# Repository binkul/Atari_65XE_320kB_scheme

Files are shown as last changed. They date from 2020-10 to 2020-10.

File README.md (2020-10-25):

# Atari_65XE_320kB_scheme

It is working, but there is problem with video. The image on the monitor is not clear. There is a lot of white vertical stripes - probably wrong GND project. 
There can be used up to four diffrent OS and eight internal languages, like MAC65, Action!, Basic XE, XL. On Board GTIA fixer and 256kB extra RAM.

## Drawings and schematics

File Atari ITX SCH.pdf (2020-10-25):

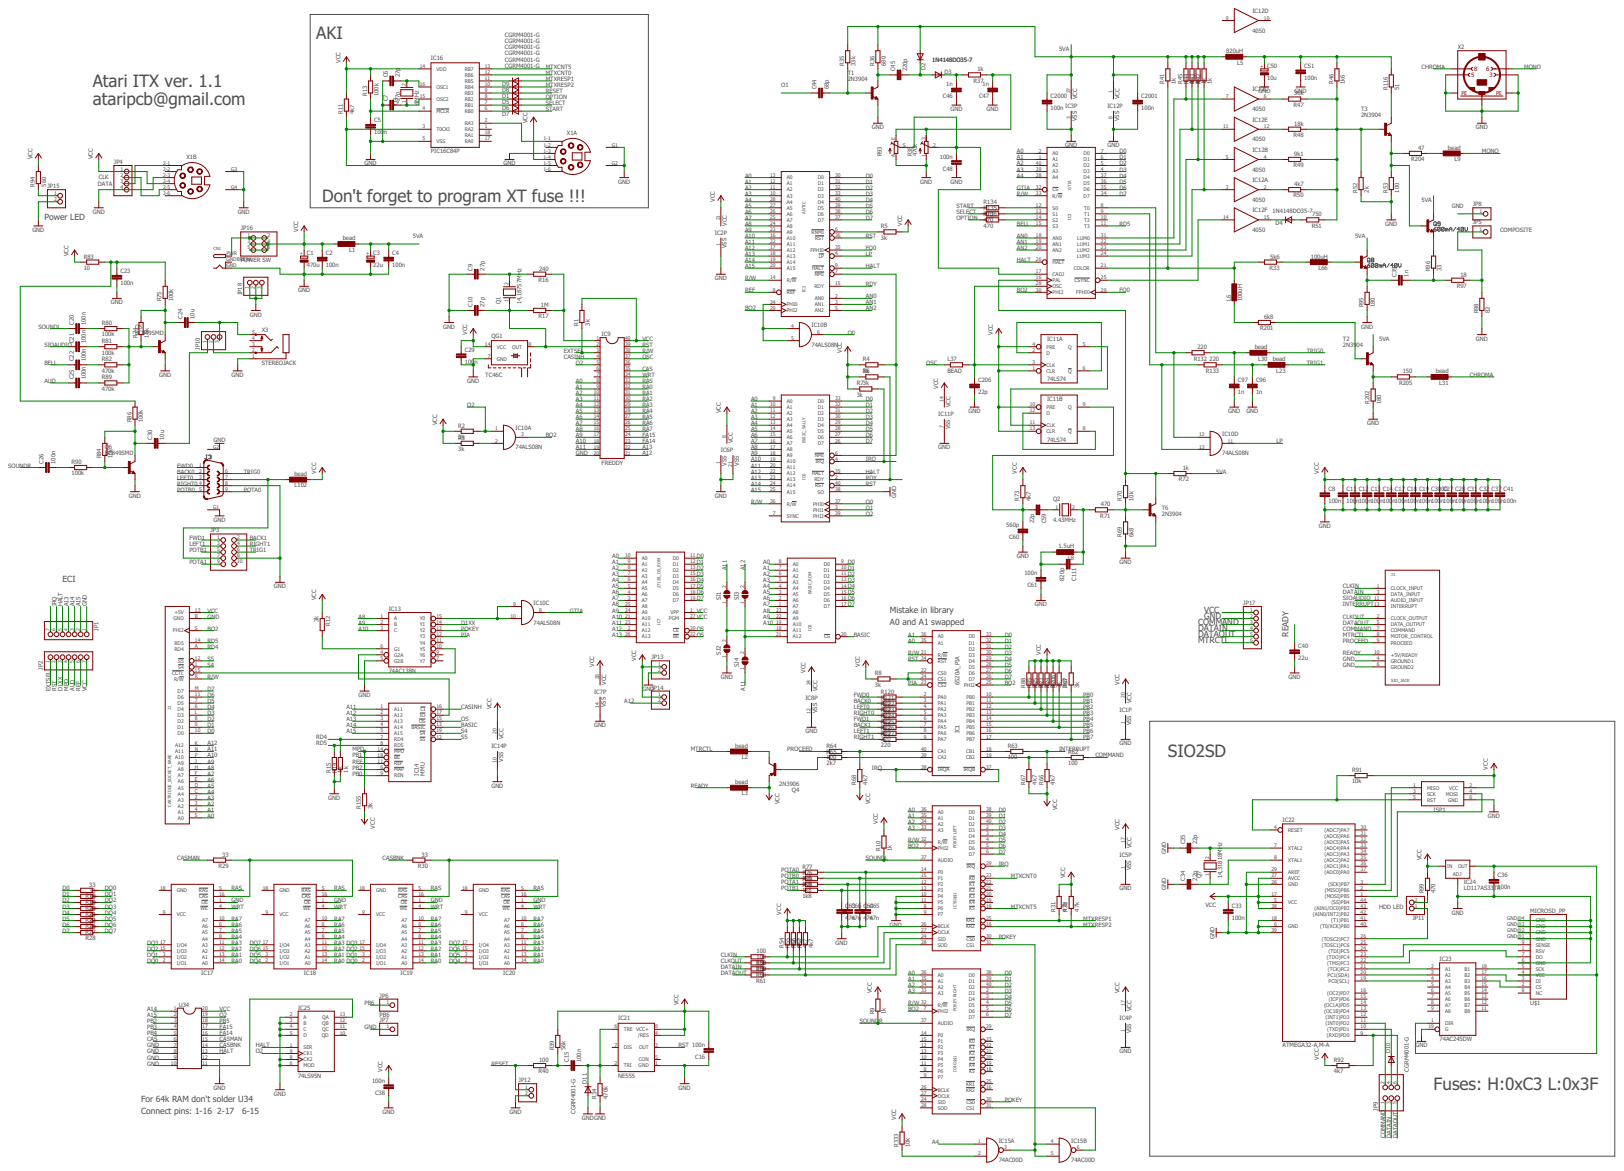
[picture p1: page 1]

Don't forget to program XT fuse !!!

VSS VSS VCC VSS

VCC VSS

For 64k RAM don't solder U34
Connect pins: 1-16 2-17 6-15

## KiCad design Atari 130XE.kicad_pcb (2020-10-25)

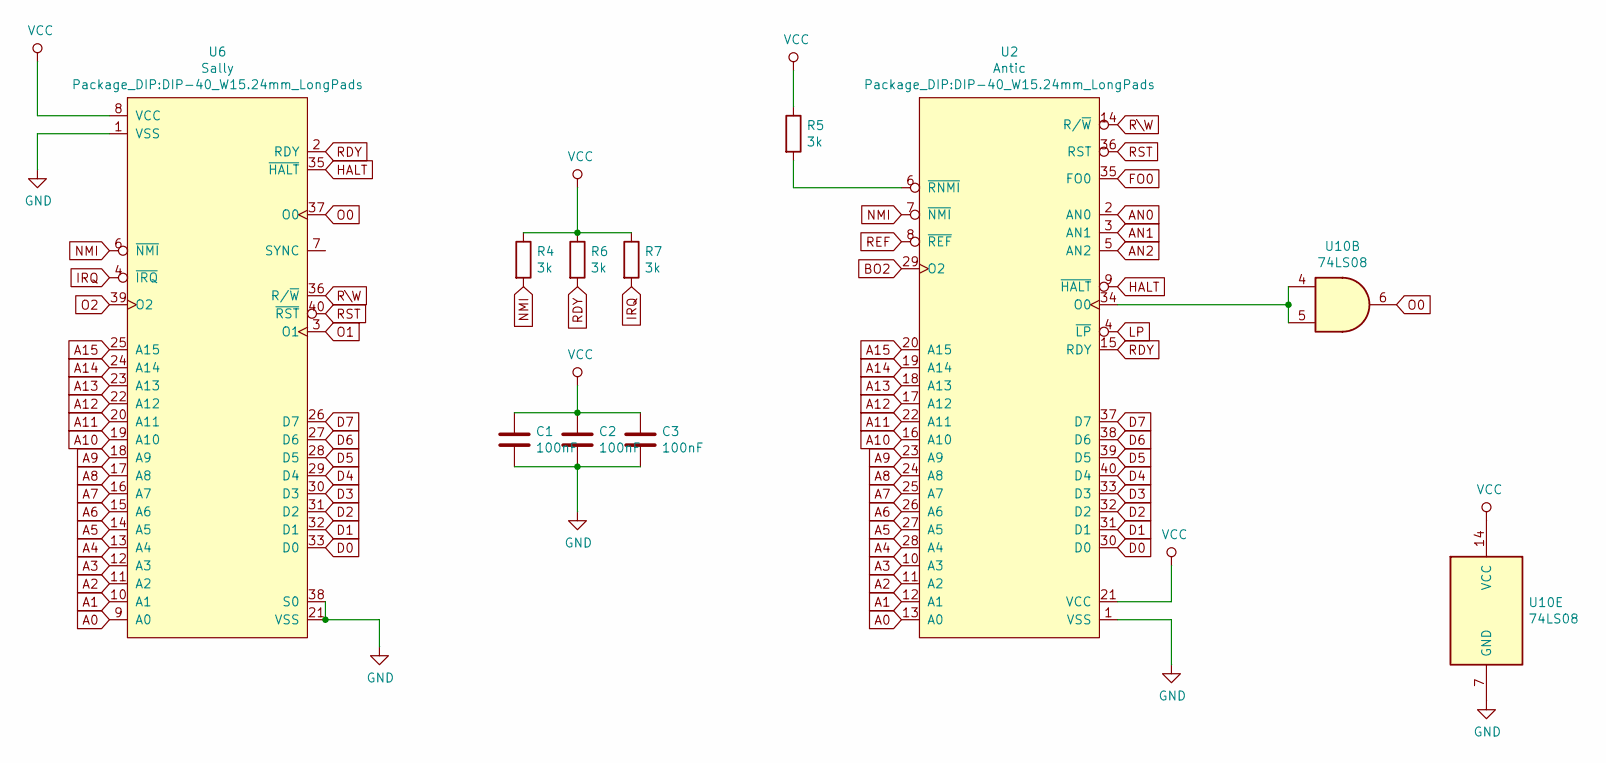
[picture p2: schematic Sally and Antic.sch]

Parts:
C1, C2, C3: 100nF; C_Disc_D5.0mm_W2.5mm_P5.00mm
R4, R5, R6, R7: 3k; R_1206_3216Metric_Pad1.42x1.75mm_HandSolder
U2: Antic; DIP-40_W15.24mm_LongPads
U6: Sally; DIP-40_W15.24mm_LongPads
U10: 74LS08; DIP-14_W7.62mm_Socket

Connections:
A0: U2.13 (A0), U6.9 (A0); also elsewhere on the board
A1: U2.12 (A1), U6.10 (A1); also elsewhere on the board
A2: U2.11 (A2), U6.11 (A2); also elsewhere on the board
A3: U2.10 (A3), U6.12 (A3); also elsewhere on the board
A4: U2.28 (A4), U6.13 (A4); also elsewhere on the board
A5: U2.27 (A5), U6.14 (A5); also elsewhere on the board
A6: U2.26 (A6), U6.15 (A6); also elsewhere on the board
A7: U2.25 (A7), U6.16 (A7); also elsewhere on the board
A8: U2.24 (A8), U6.17 (A8); also elsewhere on the board
A9: U2.23 (A9), U6.18 (A9); also elsewhere on the board
A10: U2.16 (A10), U6.19 (A10); also elsewhere on the board
A11: U2.22 (A11), U6.20 (A11); also elsewhere on the board
A12: U2.17 (A12), U6.22 (A12); also elsewhere on the board
A13: U2.18 (A13), U6.23 (A13); also elsewhere on the board
A14: U2.19 (A14), U6.24 (A14); also elsewhere on the board
A15: U2.20 (A15), U6.25 (A15); also elsewhere on the board
AN0: U2.2 (AN0); also elsewhere on the board
AN1: U2.3 (AN1); also elsewhere on the board
AN2: U2.5 (AN2); also elsewhere on the board
BO2: U2.29 (O2); also elsewhere on the board
D0: U2.30 (D0), U6.33 (D0); also elsewhere on the board
D1: U2.31 (D1), U6.32 (D1); also elsewhere on the board
D2: U2.32 (D2), U6.31 (D2); also elsewhere on the board
D3: U2.33 (D3), U6.30 (D3); also elsewhere on the board
D4: U2.40 (D4), U6.29 (D4); also elsewhere on the board
D5: U2.39 (D5), U6.28 (D5); also elsewhere on the board
D6: U2.38 (D6), U6.27 (D6); also elsewhere on the board
D7: U2.37 (D7), U6.26 (D7); also elsewhere on the board
FO0: U2.35 (FO0); also elsewhere on the board
GND: C1.2, C2.2, C3.2, U2.1 (VSS), U6.1 (VSS), U6.21 (VSS), U6.38 (S0), U10.7 (GND); also elsewhere on the board
HALT: U2.9 (~HALT), U6.35 (~HALT); also elsewhere on the board
IRQ: R7.2, U6.4 (~IRQ); also elsewhere on the board
LP: U2.4 (~LP); also elsewhere on the board
NMI: R4.2, U2.7 (~NMI), U6.6 (~NMI)
unnamed: R5.2, U2.6 (~RNMI)
unnamed: U2.34 (O0), U10.4, U10.5
O0: U6.37 (O0), U10.6
O1: U6.3 (O1); also elsewhere on the board
O2: U6.39 (O2); also elsewhere on the board
RDY: R6.2, U2.15 (RDY), U6.2 (RDY)
REF: U2.8 (~REF); also elsewhere on the board
RST: U2.36 (RST), U6.40 (~RST); also elsewhere on the board
R\W: U2.14 (R/~W), U6.36 (R/~W); also elsewhere on the board
VCC: C1.1, C2.1, C3.1, R4.1, R5.1, R6.1, R7.1, U2.21 (VCC), U6.8 (VCC), U10.14 (VCC); also elsewhere on the board

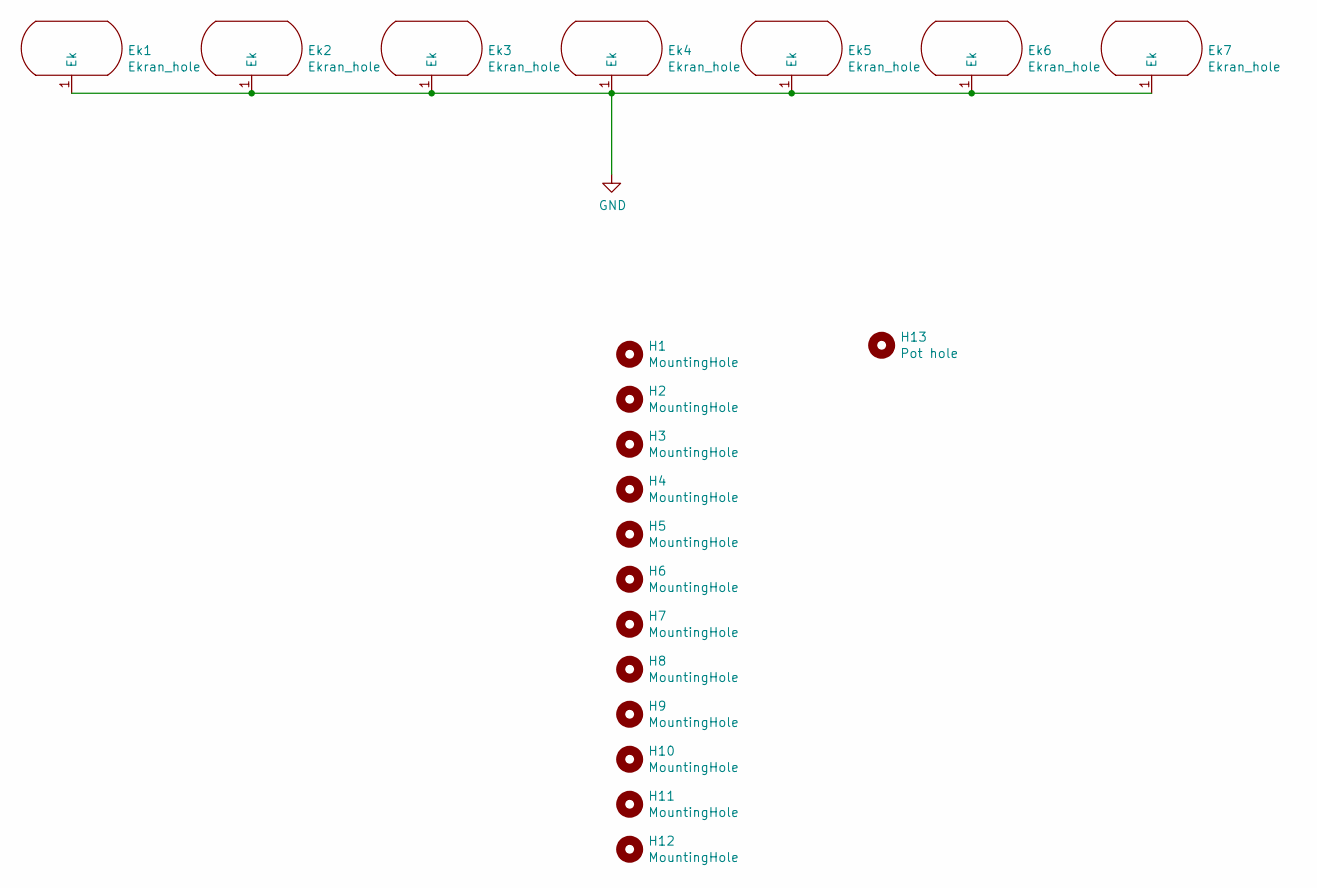
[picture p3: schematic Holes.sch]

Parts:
Ek1, Ek2, Ek3, Ek4, Ek5, Ek6, Ek7: Ekran_hole; Ekran_GND
H1, H2: MountingHole; Big_hole
H3, H4: MountingHole; Medium_hole
H5, H6, H7, H10, H11, H12: MountingHole; Hole_3.4mm
H8, H9: MountingHole; Hole_4.4mm
H13: Pot hole; MountingHole_3.2mm_M3

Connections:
GND: Ek1.1, Ek2.1, Ek3.1, Ek4.1, Ek5.1, Ek6.1, Ek7.1; also elsewhere on the board

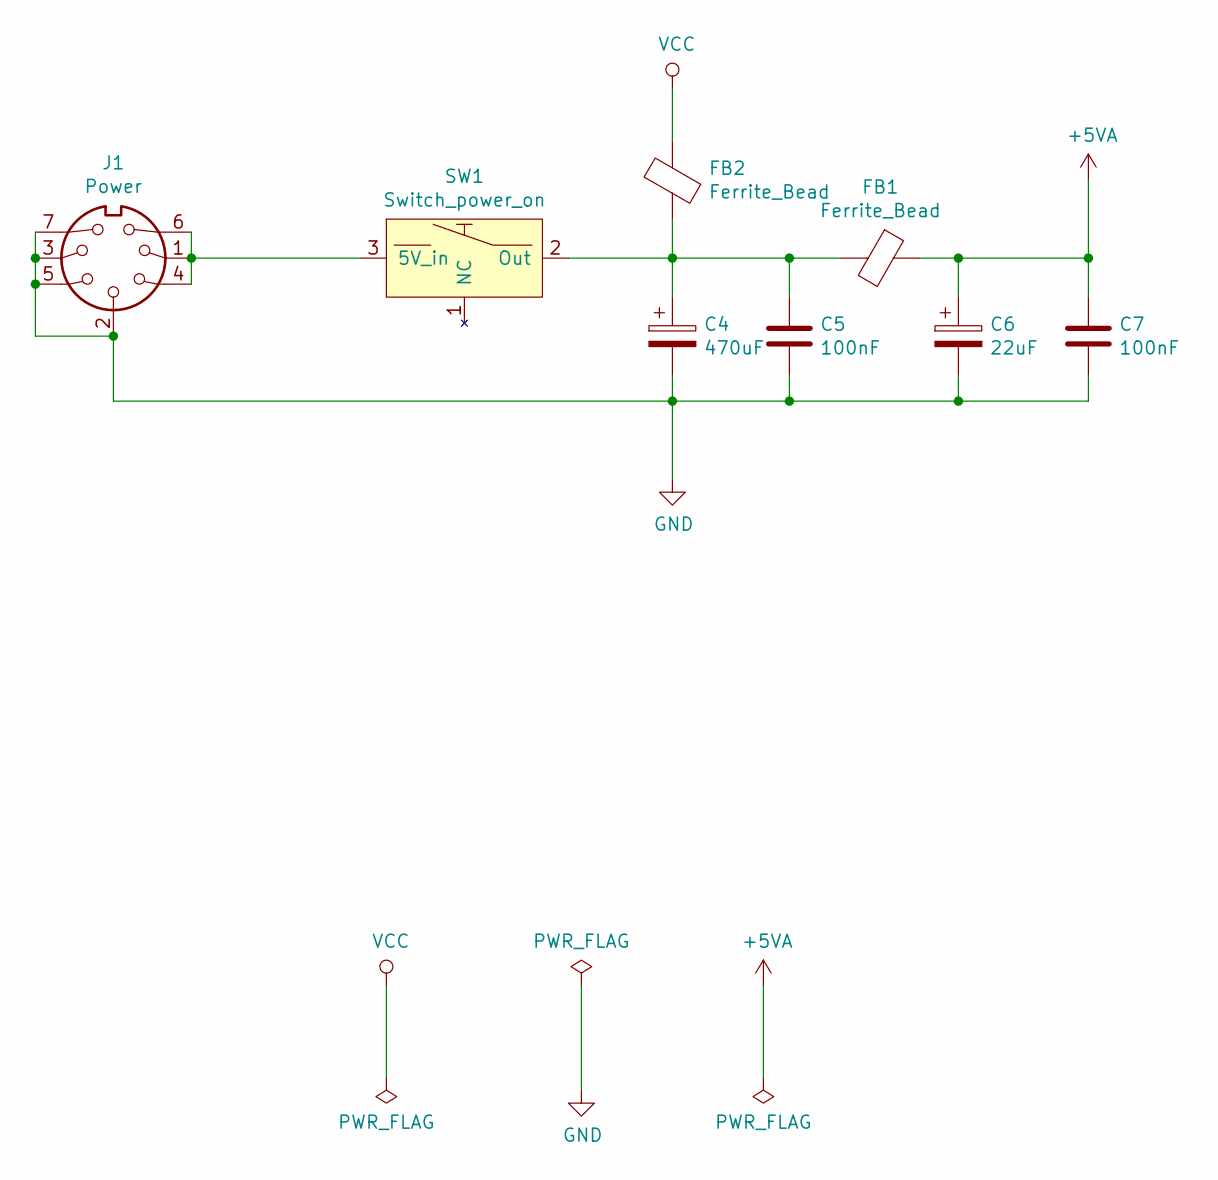
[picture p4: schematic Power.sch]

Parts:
C4: 470uF; CP_Radial_D10.0mm_P5.00mm
C5, C7: 100nF; C_Disc_D5.0mm_W2.5mm_P5.00mm
C6: 22uF; CP_Radial_D5.0mm_P2.00mm
FB1, FB2: Ferrite_Bead; L_Axial_L9.5mm_D4.0mm_P12.70mm_Horizontal_Fastron_SMCC
J1: Power; DIN_7_pin
SW1: Switch_power_on; Switch_ON-OFF

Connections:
+5VA: C6.1, C7.1, FB1.1; also elsewhere on the board
GND: C4.2, C5.2, C6.2, C7.2, J1.2, J1.3, J1.5, J1.7; also elsewhere on the board
unnamed: C4.1, C5.1, FB1.2, FB2.1, SW1.2 (Out)
unnamed: J1.1, J1.4, J1.6, SW1.3 (5V_in)
VCC: FB2.2; also elsewhere on the board

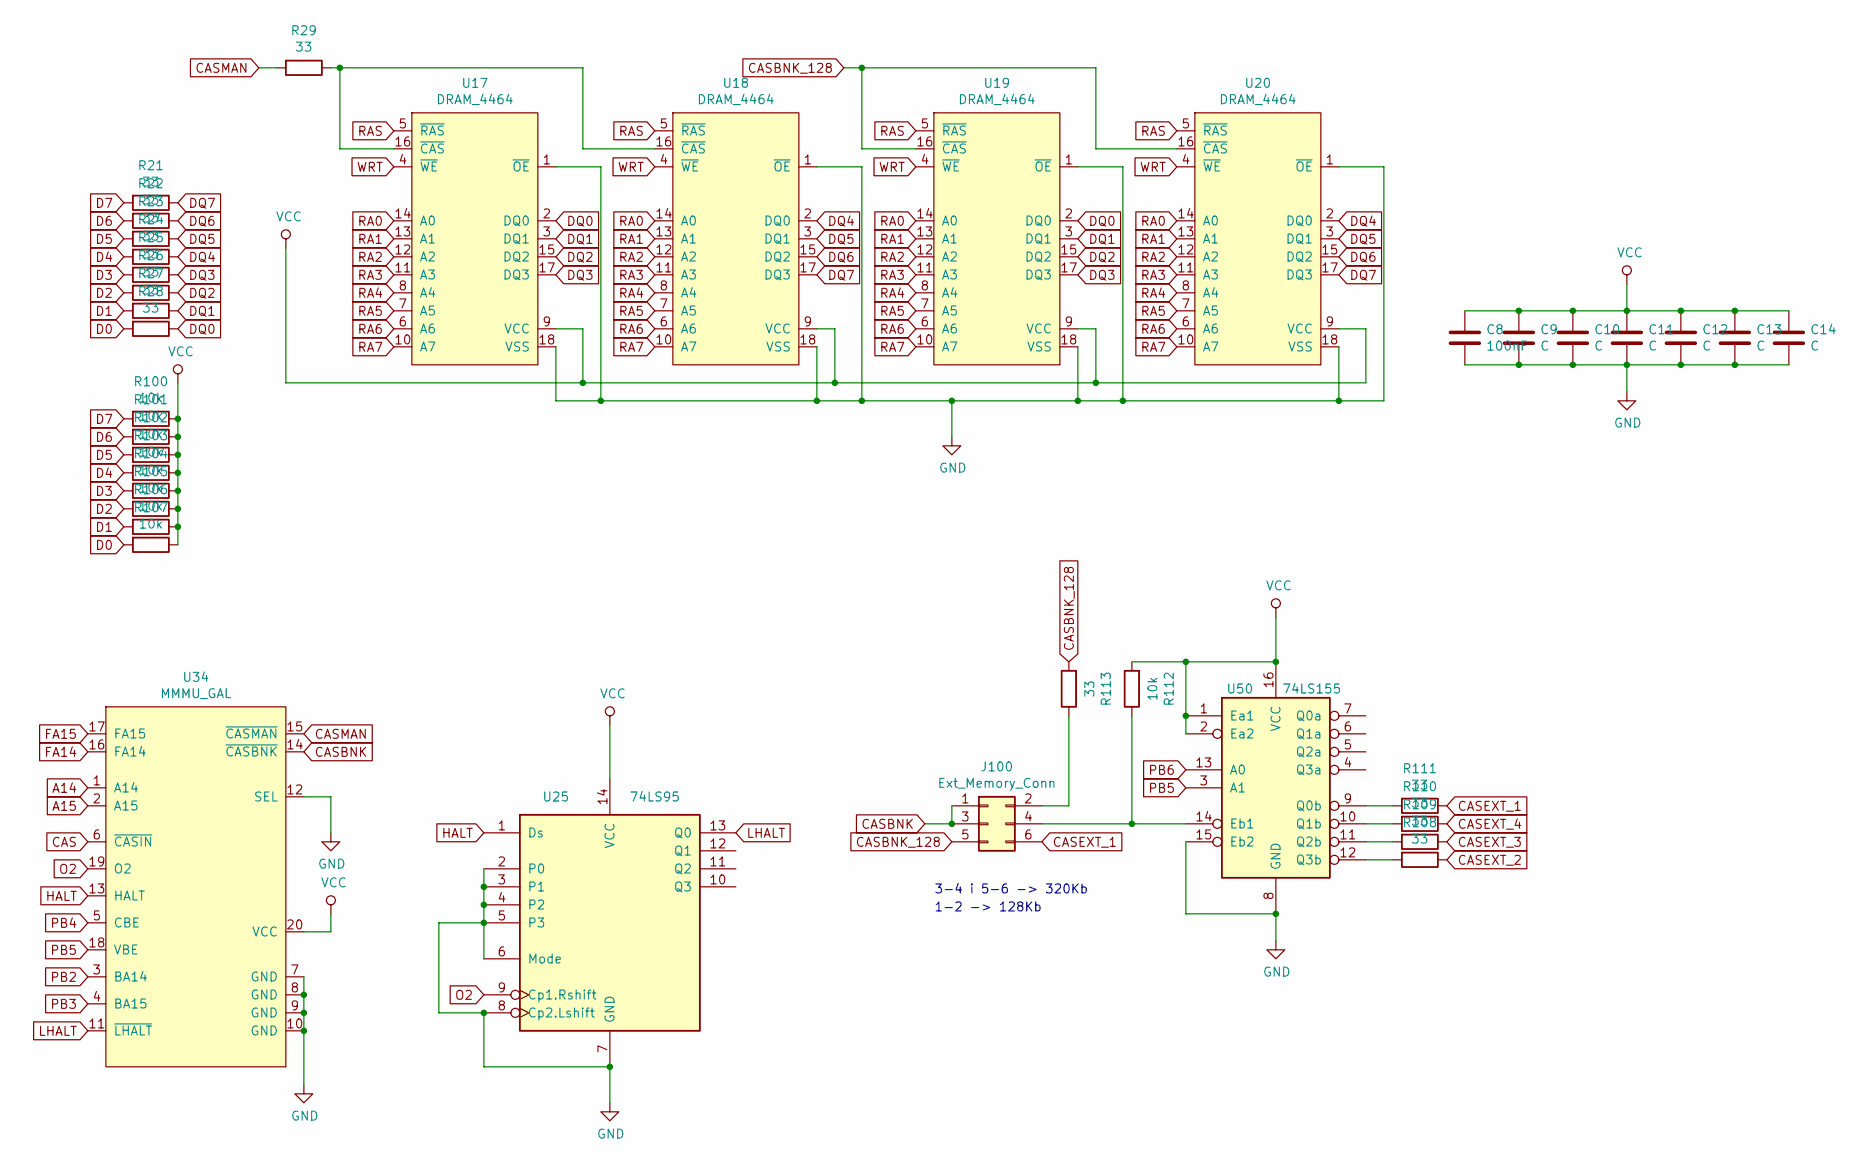
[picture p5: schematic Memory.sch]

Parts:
C8: 100nF; C_Disc_D5.0mm_W2.5mm_P5.00mm
C9, C10, C11, C12, C13, C14: C; C_Disc_D5.0mm_W2.5mm_P5.00mm
J100: Ext_Memory_Conn; PinHeader_2x03_P2.54mm_Vertical
R21, R22, R23, R24, R25, R26, R27, R28, R29, R108, R109, R110, R111, R113: 33; R_1206_3216Metric_Pad1.42x1.75mm_HandSolder
R100, R101, R102, R103, R104, R105, R106, R107, R112: 10k; R_1206_3216Metric_Pad1.42x1.75mm_HandSolder
U17, U18, U19, U20: DRAM_4464; DIP-18_W7.62mm_LongPads
U25: 74LS95; DIP-14_W7.62mm_Socket
U34: MMMU_GAL; DIP-20_W7.62mm_Socket
U50: 74LS155; DIP-16_W7.62mm_Socket

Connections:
A14: U34.1 (A14); also elsewhere on the board
A15: U34.2 (A15); also elsewhere on the board
CAS: U34.6 (~CASIN); also elsewhere on the board
CASBNK: J100.1, J100.3, U34.14 (~CASBNK)
CASBNK_128: J100.5, R113.2, U19.16 (~CAS), U20.16 (~CAS)
CASEXT_1: J100.6, R111.1
CASEXT_2: R108.1; also elsewhere on the board
CASEXT_3: R109.1; also elsewhere on the board
CASEXT_4: R110.1; also elsewhere on the board
CASMAN: R29.2, U34.15 (~CASMAN)
D0: R28.2, R107.2; also elsewhere on the board
D1: R27.2, R106.2; also elsewhere on the board
D2: R26.2, R105.2; also elsewhere on the board
D3: R25.2, R104.2; also elsewhere on the board
D4: R24.2, R103.2; also elsewhere on the board
D5: R23.2, R102.2; also elsewhere on the board
D6: R22.2, R101.2; also elsewhere on the board
D7: R21.2, R100.2; also elsewhere on the board
DQ0: R28.1, U17.2 (DQ0), U19.2 (DQ0); also elsewhere on the board
DQ1: R27.1, U17.3 (DQ1), U19.3 (DQ1); also elsewhere on the board
DQ2: R26.1, U17.15 (DQ2), U19.15 (DQ2); also elsewhere on the board
DQ3: R25.1, U17.17 (DQ3), U19.17 (DQ3); also elsewhere on the board
DQ4: R24.1, U18.2 (DQ0), U20.2 (DQ0); also elsewhere on the board
DQ5: R23.1, U18.3 (DQ1), U20.3 (DQ1); also elsewhere on the board
DQ6: R22.1, U18.15 (DQ2), U20.15 (DQ2); also elsewhere on the board
DQ7: R21.1, U18.17 (DQ3), U20.17 (DQ3); also elsewhere on the board
FA14: U34.16 (FA14); also elsewhere on the board
FA15: U34.17 (FA15); also elsewhere on the board
GND: C8.2, C9.2, C10.2, C11.2, C12.2, C13.2, C14.2, U17.1 (~OE), U17.18 (VSS), U18.1 (~OE), U18.18 (VSS), U19.1 (~OE), U19.18 (VSS), U20.1 (~OE), U20.18 (VSS), U25.2 (P0), U25.3 (P1), U25.4 (P2), U25.5 (P3), U25.6 (Mode), U25.7 (GND), U25.8 (Cp2.Lshift), U34.7 (GND), U34.8 (GND), U34.9 (GND), U34.10 (GND), U34.12 (SEL), U50.8 (GND), U50.15 (Eb2); also elsewhere on the board
HALT: U25.1 (Ds), U34.13 (HALT); also elsewhere on the board
LHALT: U25.13 (Q0), U34.11 (~LHALT)
unnamed: J100.2, R113.1
unnamed: J100.4, R112.1, U50.14 (Eb1)
unnamed: R29.1, U17.16 (~CAS), U18.16 (~CAS)
unnamed: R108.2, U50.12 (Q3b)
unnamed: R109.2, U50.11 (Q2b)
unnamed: R110.2, U50.10 (Q1b)
unnamed: R111.2, U50.9 (Q0b)
O2: U25.9 (Cp1.Rshift), U34.19 (O2); also elsewhere on the board
PB2: U34.3 (BA14); also elsewhere on the board
PB3: U34.4 (BA15); also elsewhere on the board
PB4: U34.5 (CBE); also elsewhere on the board
PB5: U34.18 (VBE), U50.3 (A1); also elsewhere on the board
PB6: U50.13 (A0); also elsewhere on the board
RA0: U17.14 (A0), U18.14 (A0), U19.14 (A0), U20.14 (A0); also elsewhere on the board
RA1: U17.13 (A1), U18.13 (A1), U19.13 (A1), U20.13 (A1); also elsewhere on the board
RA2: U17.12 (A2), U18.12 (A2), U19.12 (A2), U20.12 (A2); also elsewhere on the board
RA3: U17.11 (A3), U18.11 (A3), U19.11 (A3), U20.11 (A3); also elsewhere on the board
RA4: U17.8 (A4), U18.8 (A4), U19.8 (A4), U20.8 (A4); also elsewhere on the board
RA5: U17.7 (A5), U18.7 (A5), U19.7 (A5), U20.7 (A5); also elsewhere on the board
RA6: U17.6 (A6), U18.6 (A6), U19.6 (A6), U20.6 (A6); also elsewhere on the board
RA7: U17.10 (A7), U18.10 (A7), U19.10 (A7), U20.10 (A7); also elsewhere on the board
RAS: U17.5 (~RAS), U18.5 (~RAS), U19.5 (~RAS), U20.5 (~RAS); also elsewhere on the board
VCC: C8.1, C9.1, C10.1, C11.1, C12.1, C13.1, C14.1, R100.1, R101.1, R102.1, R103.1, R104.1, R105.1, R106.1, R107.1, R112.2, U17.9 (VCC), U18.9 (VCC), U19.9 (VCC), U20.9 (VCC), U25.14 (VCC), U34.20 (VCC), U50.1 (Ea1), U50.2 (Ea2), U50.16 (VCC); also elsewhere on the board
WRT: U17.4 (~WE), U18.4 (~WE), U19.4 (~WE), U20.4 (~WE); also elsewhere on the board

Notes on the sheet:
3-4 i 5-6 -> 320Kb
1-2 -> 128Kb

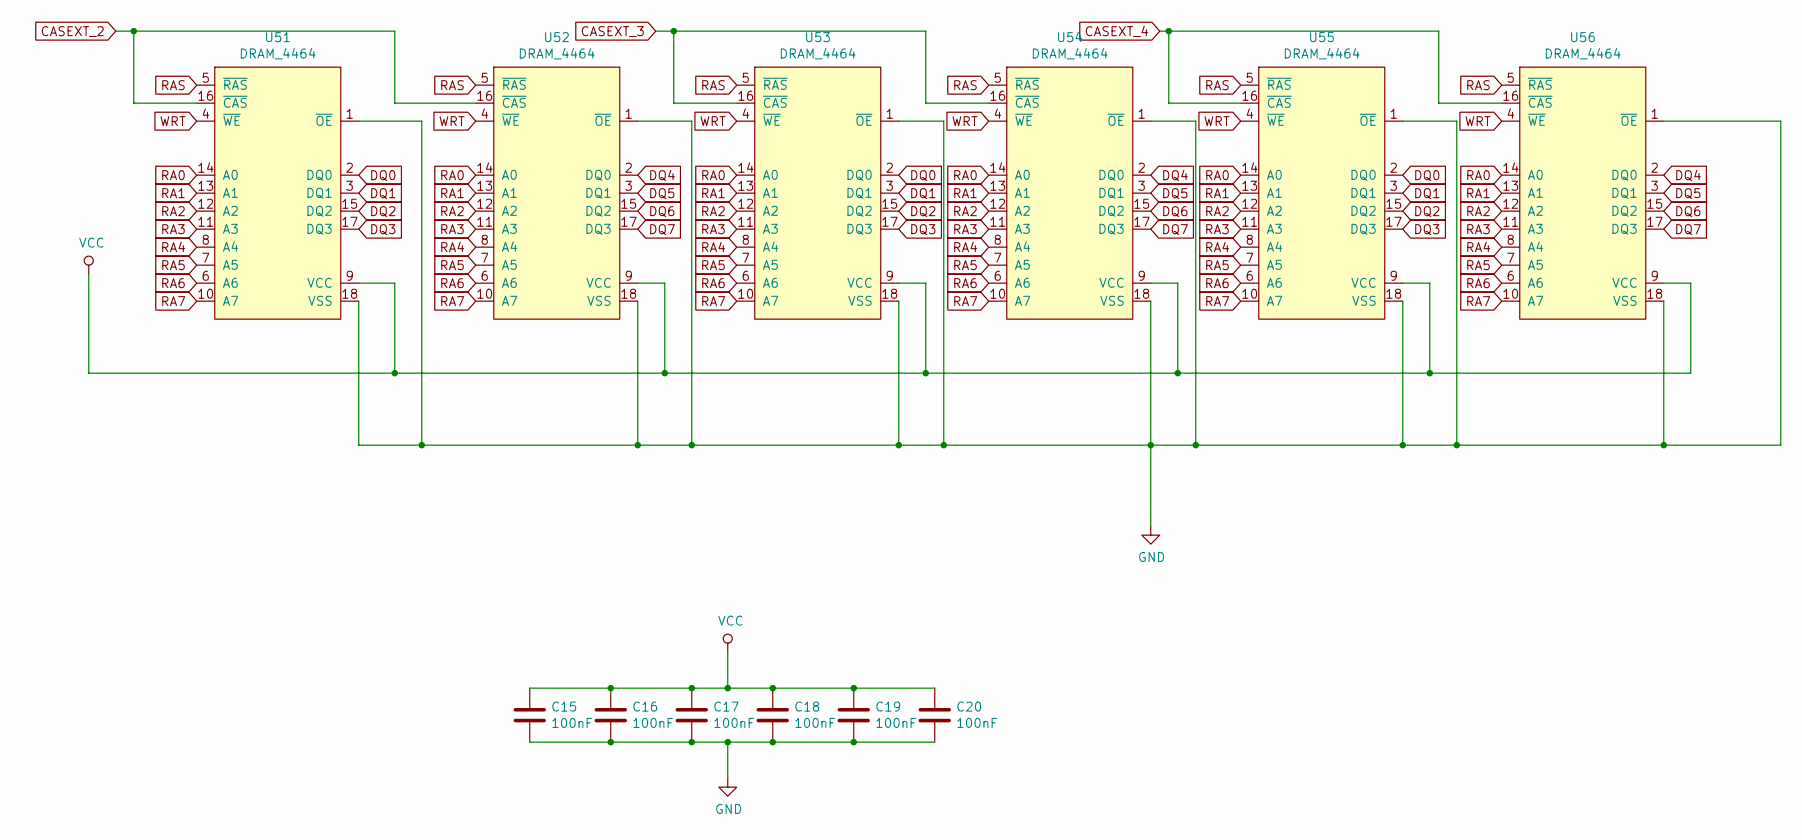
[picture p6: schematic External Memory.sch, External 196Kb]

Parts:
C15, C16, C17, C18, C19, C20: 100nF; C_Disc_D5.0mm_W2.5mm_P5.00mm
U51, U52, U53, U54, U55, U56: DRAM_4464; DIP-18_W7.62mm_LongPads

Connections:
CASEXT_2: U51.16 (~CAS), U52.16 (~CAS); also elsewhere on the board
CASEXT_3: U53.16 (~CAS), U54.16 (~CAS); also elsewhere on the board
CASEXT_4: U55.16 (~CAS), U56.16 (~CAS); also elsewhere on the board
DQ0: U51.2 (DQ0), U53.2 (DQ0), U55.2 (DQ0); also elsewhere on the board
DQ1: U51.3 (DQ1), U53.3 (DQ1), U55.3 (DQ1); also elsewhere on the board
DQ2: U51.15 (DQ2), U53.15 (DQ2), U55.15 (DQ2); also elsewhere on the board
DQ3: U51.17 (DQ3), U53.17 (DQ3), U55.17 (DQ3); also elsewhere on the board
DQ4: U52.2 (DQ0), U54.2 (DQ0), U56.2 (DQ0); also elsewhere on the board
DQ5: U52.3 (DQ1), U54.3 (DQ1), U56.3 (DQ1); also elsewhere on the board
DQ6: U52.15 (DQ2), U54.15 (DQ2), U56.15 (DQ2); also elsewhere on the board
DQ7: U52.17 (DQ3), U54.17 (DQ3), U56.17 (DQ3); also elsewhere on the board
GND: C15.2, C16.2, C17.2, C18.2, C19.2, C20.2, U51.1 (~OE), U51.18 (VSS), U52.1 (~OE), U52.18 (VSS), U53.1 (~OE), U53.18 (VSS), U54.1 (~OE), U54.18 (VSS), U55.1 (~OE), U55.18 (VSS), U56.1 (~OE), U56.18 (VSS); also elsewhere on the board
RA0: U51.14 (A0), U52.14 (A0), U53.14 (A0), U54.14 (A0), U55.14 (A0), U56.14 (A0); also elsewhere on the board
RA1: U51.13 (A1), U52.13 (A1), U53.13 (A1), U54.13 (A1), U55.13 (A1), U56.13 (A1); also elsewhere on the board
RA2: U51.12 (A2), U52.12 (A2), U53.12 (A2), U54.12 (A2), U55.12 (A2), U56.12 (A2); also elsewhere on the board
RA3: U51.11 (A3), U52.11 (A3), U53.11 (A3), U54.11 (A3), U55.11 (A3), U56.11 (A3); also elsewhere on the board
RA4: U51.8 (A4), U52.8 (A4), U53.8 (A4), U54.8 (A4), U55.8 (A4), U56.8 (A4); also elsewhere on the board
RA5: U51.7 (A5), U52.7 (A5), U53.7 (A5), U54.7 (A5), U55.7 (A5), U56.7 (A5); also elsewhere on the board
RA6: U51.6 (A6), U52.6 (A6), U53.6 (A6), U54.6 (A6), U55.6 (A6), U56.6 (A6); also elsewhere on the board
RA7: U51.10 (A7), U52.10 (A7), U53.10 (A7), U54.10 (A7), U55.10 (A7), U56.10 (A7); also elsewhere on the board
RAS: U51.5 (~RAS), U52.5 (~RAS), U53.5 (~RAS), U54.5 (~RAS), U55.5 (~RAS), U56.5 (~RAS); also elsewhere on the board
VCC: C15.1, C16.1, C17.1, C18.1, C19.1, C20.1, U51.9 (VCC), U52.9 (VCC), U53.9 (VCC), U54.9 (VCC), U55.9 (VCC), U56.9 (VCC); also elsewhere on the board
WRT: U51.4 (~WE), U52.4 (~WE), U53.4 (~WE), U54.4 (~WE), U55.4 (~WE), U56.4 (~WE); also elsewhere on the board

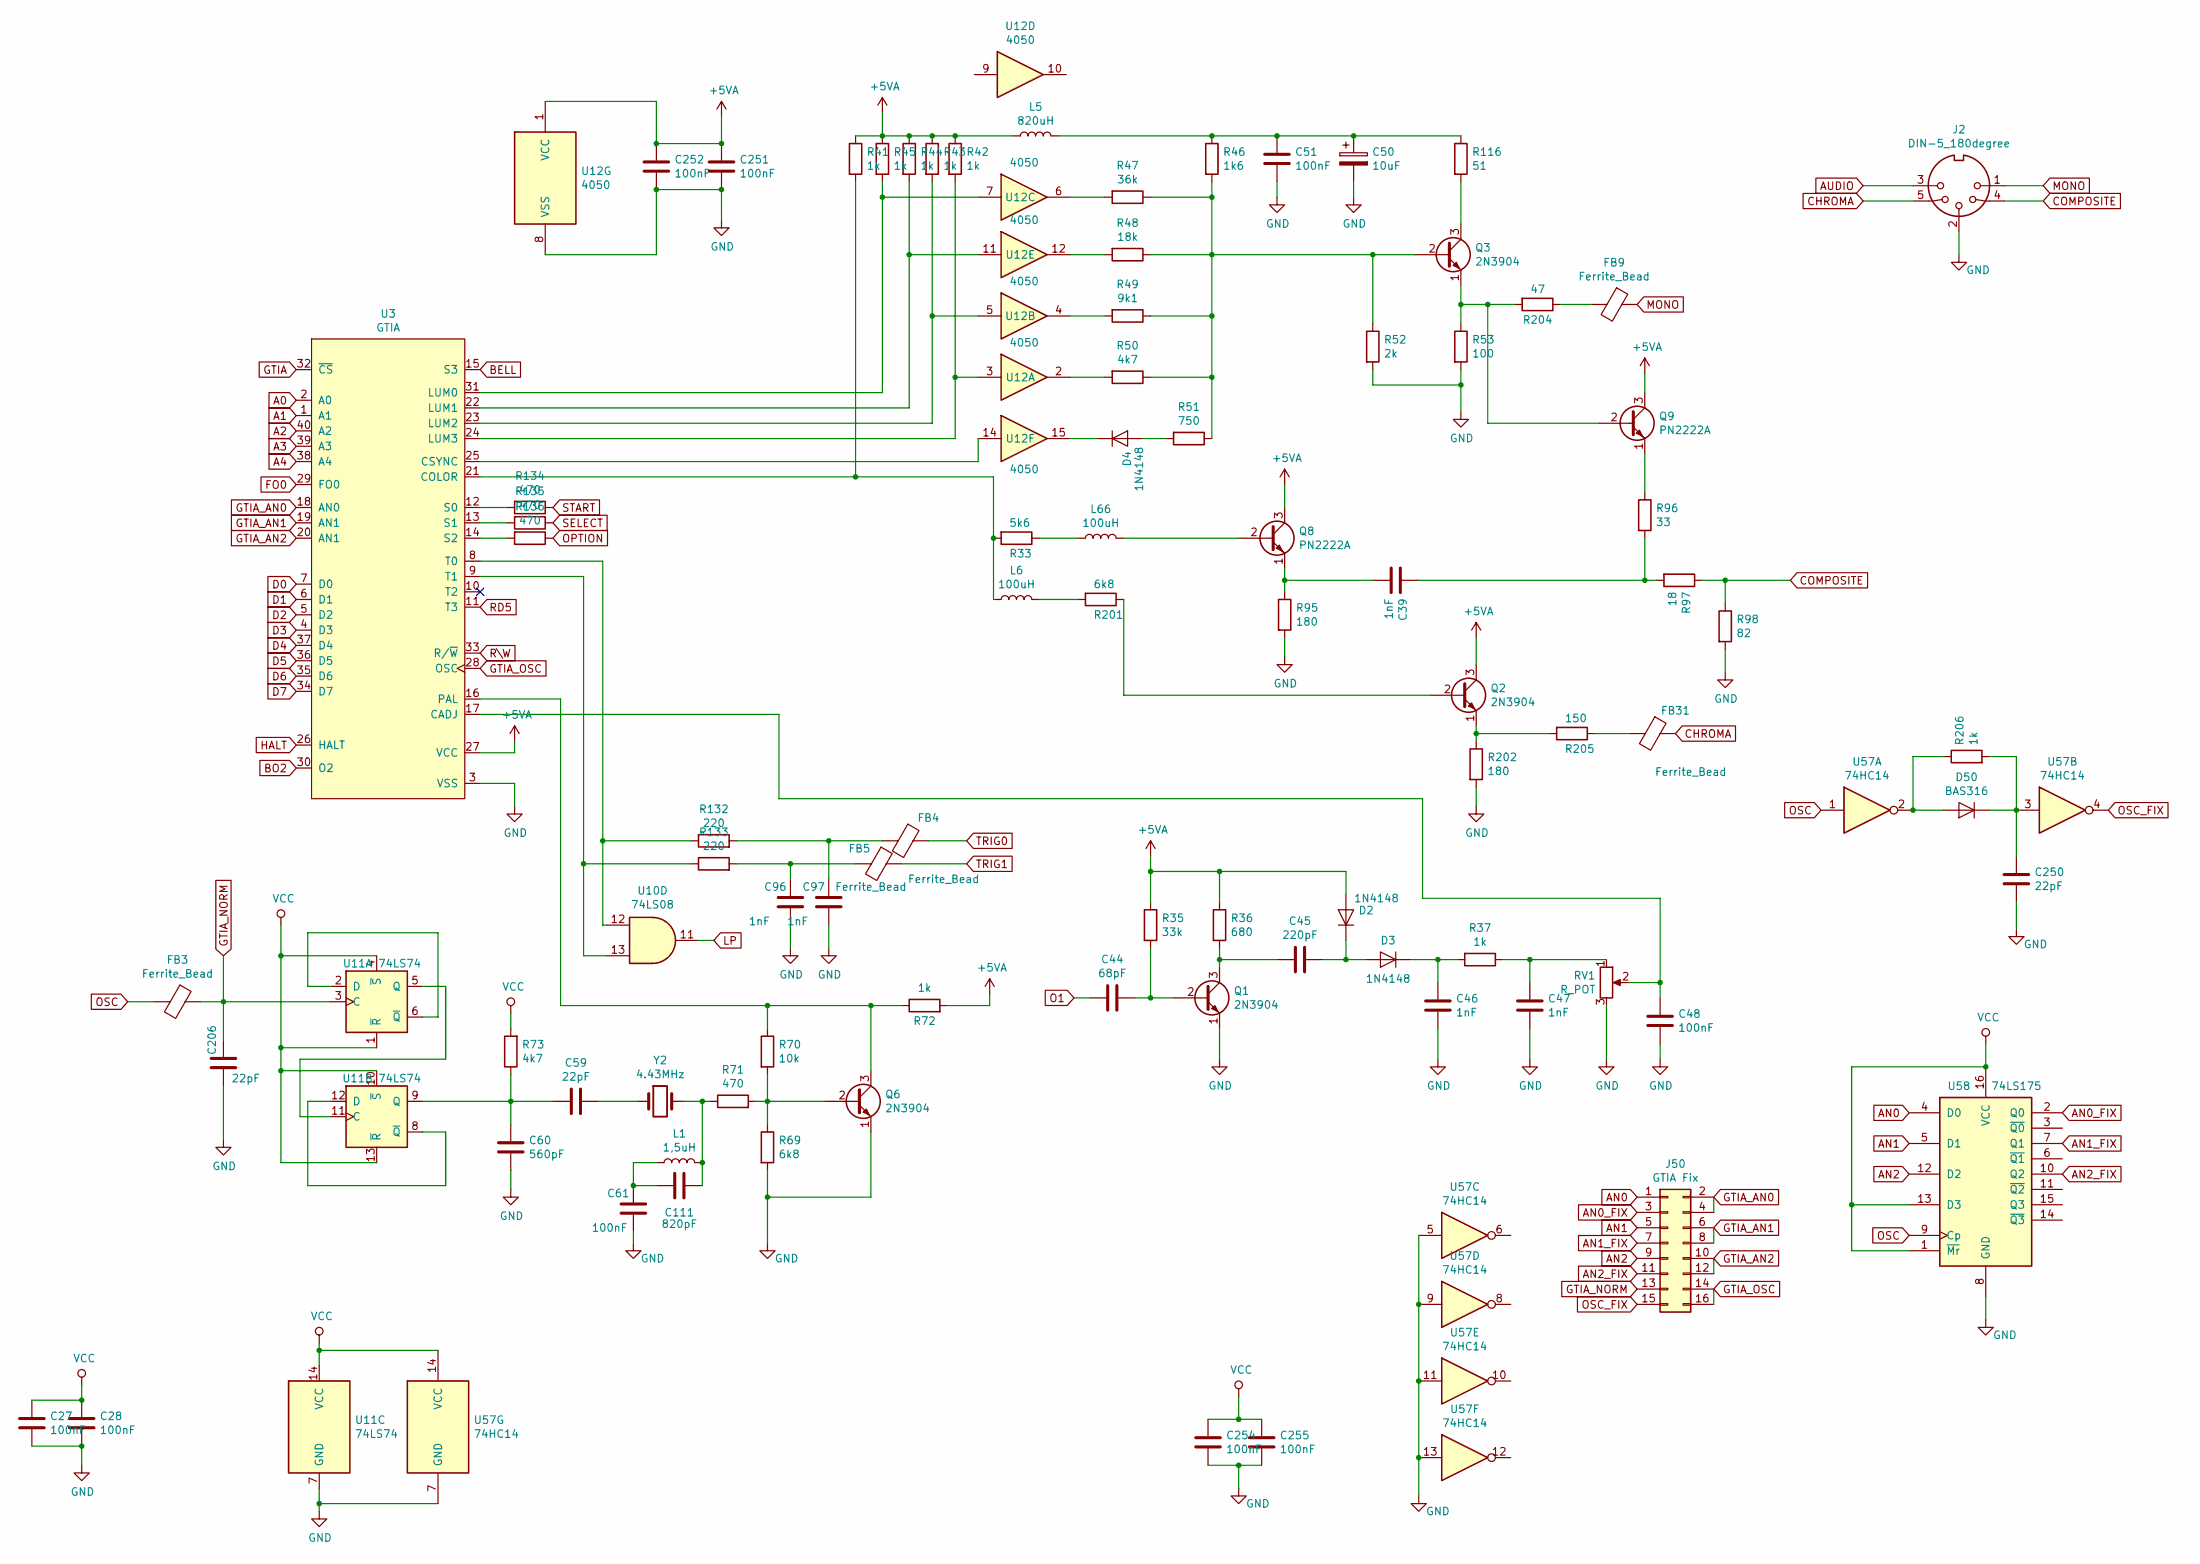
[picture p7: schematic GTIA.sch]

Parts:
C27, C28, C48, C51, C251, C252: 100nF; C_Disc_D5.0mm_W2.5mm_P5.00mm
C39: 1nF; C_1206_3216Metric_Pad1.42x1.75mm_HandSolder
C44: 68pF; C_Disc_D5.0mm_W2.5mm_P5.00mm
C45: 220pF; C_Disc_D5.0mm_W2.5mm_P5.00mm
C46, C47, C96, C97: 1nF; C_Disc_D5.0mm_W2.5mm_P5.00mm
C50: 10uF; CP_Elec_5x5.7
C59, C206, C250: 22pF; C_1206_3216Metric_Pad1.42x1.75mm_HandSolder
C60: 560pF; C_1206_3216Metric_Pad1.42x1.75mm_HandSolder
C61, C254, C255: 100nF; C_1206_3216Metric_Pad1.42x1.75mm_HandSolder
C111: 820pF; C_1206_3216Metric_Pad1.42x1.75mm_HandSolder
D2, D3, D4: 1N4148; D_MiniMELF_Handsoldering
D50: BAS316; D_SOD-323_HandSoldering
FB3, FB4, FB5, FB9, FB31: Ferrite_Bead; L_Axial_L9.5mm_D4.0mm_P12.70mm_Horizontal_Fastron_SMCC
J2: DIN-5_180degree; DIN_5_pin
J50: GTIA Fix; PinHeader_2x08_P2.54mm_Vertical
L1: 1,5uH; L_1812_4532Metric_Pad1.30x3.40mm_HandSolder
L5: 820uH; R_1812_4532Metric_Pad1.30x3.40mm_HandSolder
L6, L66: 100uH; L_1812_4532Metric_Pad1.30x3.40mm_HandSolder
Q1, Q2, Q3, Q6: 2N3904; TO-92
Q8, Q9: PN2222A; TO-92_Inline
R33: 5k6; R_1206_3216Metric_Pad1.42x1.75mm_HandSolder
R35: 33k; R_1206_3216Metric_Pad1.42x1.75mm_HandSolder
R36: 680; R_1206_3216Metric_Pad1.42x1.75mm_HandSolder
R37, R41, R42, R43, R44, R45, R72, R206: 1k; R_1206_3216Metric_Pad1.42x1.75mm_HandSolder
R46: 1k6; R_1206_3216Metric_Pad1.42x1.75mm_HandSolder
R47: 36k; R_1206_3216Metric_Pad1.42x1.75mm_HandSolder
R48: 18k; R_1206_3216Metric_Pad1.42x1.75mm_HandSolder
R49: 9k1; R_1206_3216Metric_Pad1.42x1.75mm_HandSolder
R50, R73: 4k7; R_1206_3216Metric_Pad1.42x1.75mm_HandSolder
R51: 750; R_1206_3216Metric_Pad1.42x1.75mm_HandSolder
R52: 2k; R_1206_3216Metric_Pad1.42x1.75mm_HandSolder
R53: 100; R_1206_3216Metric_Pad1.42x1.75mm_HandSolder
R69, R201: 6k8; R_1206_3216Metric_Pad1.42x1.75mm_HandSolder
R70: 10k; R_1206_3216Metric_Pad1.42x1.75mm_HandSolder
R71, R134, R135, R136: 470; R_1206_3216Metric_Pad1.42x1.75mm_HandSolder
R95, R202: 180; R_1206_3216Metric_Pad1.42x1.75mm_HandSolder
R96: 33; R_1206_3216Metric_Pad1.42x1.75mm_HandSolder
R97: 18; R_1206_3216Metric_Pad1.42x1.75mm_HandSolder
R98: 82; R_1206_3216Metric_Pad1.42x1.75mm_HandSolder
R116: 51; R_1206_3216Metric_Pad1.42x1.75mm_HandSolder
R132, R133: 220; R_1206_3216Metric_Pad1.42x1.75mm_HandSolder
R204: 47; R_1206_3216Metric_Pad1.42x1.75mm_HandSolder
R205: 150; R_1206_3216Metric_Pad1.42x1.75mm_HandSolder
RV1: R_POT; Potentiometer_ACP_CA9-V10_Vertical_Hole
U3: GTIA; DIP-40_W15.24mm_LongPads
U10: 74LS08; DIP-14_W7.62mm_Socket
U11: 74LS74; DIP-14_W7.62mm_Socket
U12: 4050; DIP-16_W7.62mm_Socket
U57: 74HC14; SOIC-14_3.9x8.7mm_P1.27mm
U58: 74LS175; SOIC-16_3.9x9.9mm_P1.27mm
Y2: 4.43MHz; Crystal_HC18-U_Horizontal

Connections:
+5VA: C251.1, C252.1, D2.2 (A), L5.1, Q2.3 (C), Q8.3 (C), Q9.3 (C), R35.1, R36.1, R41.1, R42.1, R43.1, R44.1, R45.1, R72.2, U3.27 (VCC), U12.1 (VCC); also elsewhere on the board
A0: U3.2 (A0); also elsewhere on the board
A1: U3.1 (A1); also elsewhere on the board
A2: U3.40 (A2); also elsewhere on the board
A3: U3.39 (A3); also elsewhere on the board
A4: U3.38 (A4); also elsewhere on the board
AN0: J50.1, U58.4 (D0); also elsewhere on the board
AN0_FIX: J50.3, U58.2 (Q0)
AN1: J50.5, U58.5 (D1); also elsewhere on the board
AN1_FIX: J50.7, U58.7 (Q1)
AN2: J50.9, U58.12 (D2); also elsewhere on the board
AN2_FIX: J50.11, U58.10 (Q2)
AUDIO: J2.3; also elsewhere on the board
BELL: U3.15 (S3); also elsewhere on the board
BO2: U3.30 (O2); also elsewhere on the board
CHROMA: FB31.1, J2.5
COMPOSITE: J2.4, R97.1, R98.1
D0: U3.7 (D0); also elsewhere on the board
D1: U3.6 (D1); also elsewhere on the board
D2: U3.5 (D2); also elsewhere on the board
D3: U3.4 (D3); also elsewhere on the board
D4: U3.37 (D4); also elsewhere on the board
D5: U3.36 (D5); also elsewhere on the board
D6: U3.35 (D6); also elsewhere on the board
D7: U3.34 (D7); also elsewhere on the board
FO0: U3.29 (FO0); also elsewhere on the board
GND: C27.2, C28.2, C46.1, C47.1, C48.1, C50.2, C51.1, C60.2, C61.2, C96.2, C97.2, C206.2, C250.1, C251.2, C252.2, C254.2, C255.2, J2.2, Q1.1 (E), Q6.1 (E), R52.2, R53.2, R69.2, R95.2, R98.2, R202.2, RV1.3, U3.3 (VSS), U11.7 (GND), U12.8 (VSS), U57.5, U57.7 (GND), U57.9, U57.11, U57.13, U58.8 (GND); also elsewhere on the board
GTIA: U3.32 (~CS); also elsewhere on the board
GTIA_AN0: J50.2, J50.4, U3.18 (AN0)
GTIA_AN1: J50.6, J50.8, U3.19 (AN1)
GTIA_AN2: J50.10, J50.12, U3.20 (AN1)
GTIA_NORM: C206.1, FB3.1, J50.13, U11.3 (C)
GTIA_OSC: J50.14, J50.16, U3.28 (OSC)
HALT: U3.26 (HALT); also elsewhere on the board
LP: U10.11; also elsewhere on the board
MONO: FB9.1, J2.1
unnamed: C39.1, Q8.1 (E), R95.1
unnamed: C39.2, R96.2, R97.2
unnamed: C44.1, Q1.2 (B), R35.2
unnamed: C45.1, D2.1 (K), D3.2 (A)
unnamed: C45.2, Q1.3 (C), R36.2
unnamed: C46.2, D3.1 (K), R37.2
unnamed: C47.2, R37.1, RV1.1
unnamed: C48.2, RV1.2, U3.17 (CADJ)
unnamed: C50.1, C51.2, L5.2, R46.1, R116.1
unnamed: C59.1, Y2.1
unnamed: C59.2, C60.1, R73.1, U11.9 (Q)
unnamed: C96.1, FB5.2, R133.2
unnamed: C97.1, FB4.2, R132.2
unnamed: C111.1, L1.2, R71.1, Y2.2
unnamed: C61.1, C111.2, L1.1
unnamed: C250.2, D50.1 (K), R206.2, U57.3
unnamed: D4.1 (K), U12.15
unnamed: D4.2 (A), R51.2
unnamed: D50.2 (A), R206.1, U57.2
unnamed: FB9.2, R204.1
unnamed: FB31.2, R205.1
unnamed: L6.1, R33.2, R41.2, U3.21 (COLOR)
unnamed: L6.2, R201.2
unnamed: L66.1, R33.1
unnamed: L66.2, Q8.2 (B)
unnamed: Q2.1 (E), R202.1, R205.2
unnamed: Q2.2 (B), R201.1
unnamed: Q3.1 (E), Q9.2 (B), R53.1, R204.2
unnamed: Q3.2 (B), R46.2, R47.1, R48.1, R49.1, R50.1, R51.1, R52.1
unnamed: Q3.3 (C), R116.2
unnamed: Q6.2 (B), R69.1, R70.2, R71.2
unnamed: Q6.3 (C), R70.1, R72.1, U3.16 (PAL)
unnamed: Q9.1 (E), R96.1
unnamed: R42.2, U3.24 (LUM3), U12.3
unnamed: R43.2, U3.23 (LUM2), U12.5
unnamed: R44.2, U3.22 (LUM1), U12.11
unnamed: R45.2, U3.31 (LUM0), U12.7
unnamed: R47.2, U12.6
unnamed: R48.2, U12.12
unnamed: R49.2, U12.4
unnamed: R50.2, U12.2
unnamed: R132.1, U3.8 (T0), U10.12
unnamed: R133.1, U3.9 (T1), U10.13
unnamed: R134.2, U3.12 (S0)
unnamed: R135.2, U3.13 (S1)
unnamed: R136.2, U3.14 (S2)
unnamed: U11.2 (D), U11.6 (~Q)
unnamed: U11.5 (Q), U11.11 (C)
unnamed: U11.8 (~Q), U11.12 (D)
unnamed: U3.25 (CSYNC), U12.14
O1: C44.2; also elsewhere on the board
OPTION: R136.1; also elsewhere on the board
OSC: FB3.2, U57.1, U58.9 (Cp); also elsewhere on the board
OSC_FIX: J50.15, U57.4
RD5: U3.11 (T3); also elsewhere on the board
R\W: U3.33 (R/~W); also elsewhere on the board
SELECT: R135.1; also elsewhere on the board
START: R134.1; also elsewhere on the board
TRIG0: FB4.1; also elsewhere on the board
TRIG1: FB5.1; also elsewhere on the board
VCC: C27.1, C28.1, C254.1, C255.1, R73.2, U11.1 (~R), U11.4 (~S), U11.10 (~S), U11.13 (~R), U11.14 (VCC), U57.14 (VCC), U58.1 (~Mr), U58.13 (D3), U58.16 (VCC); also elsewhere on the board

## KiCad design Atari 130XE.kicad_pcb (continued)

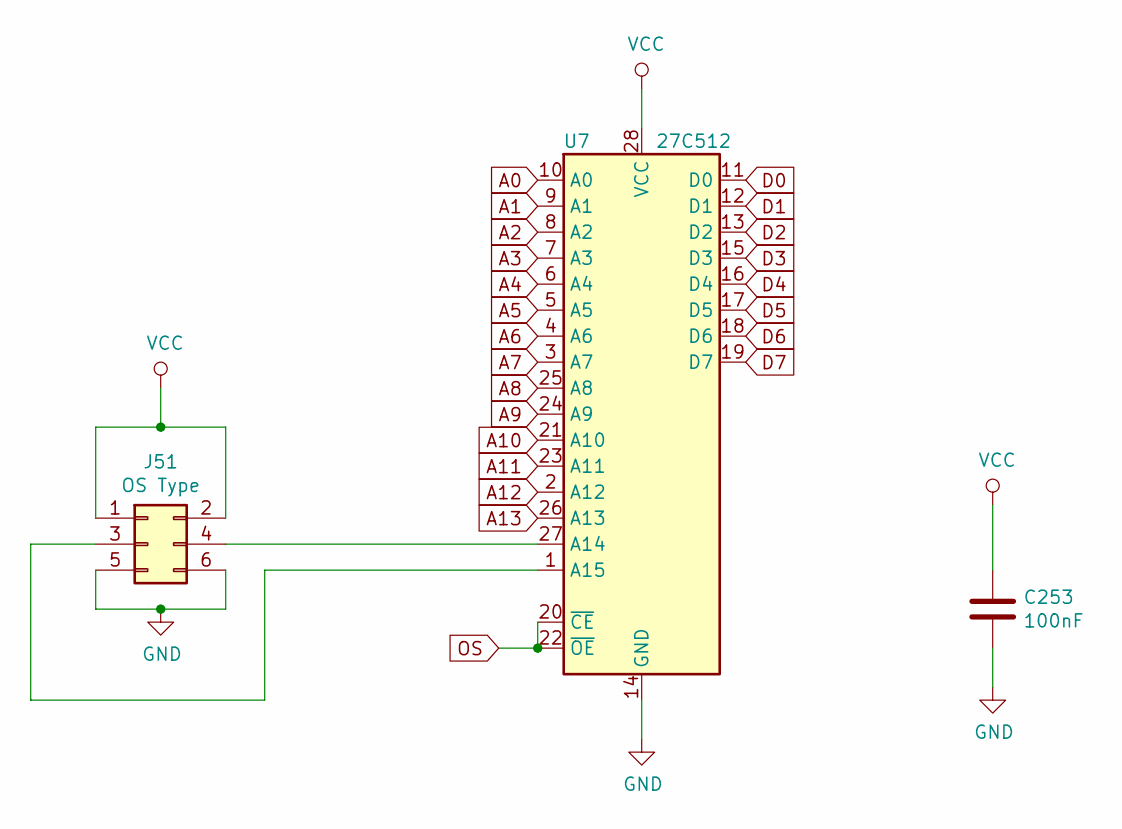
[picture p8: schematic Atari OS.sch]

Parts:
C253: 100nF; C_Disc_D5.0mm_W2.5mm_P5.00mm
J51: OS Type; PinHeader_2x03_P2.54mm_Vertical
U7: 27C512; DIP-28_W15.24mm_LongPads

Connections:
A0: U7.10 (A0); also elsewhere on the board
A1: U7.9 (A1); also elsewhere on the board
A2: U7.8 (A2); also elsewhere on the board
A3: U7.7 (A3); also elsewhere on the board
A4: U7.6 (A4); also elsewhere on the board
A5: U7.5 (A5); also elsewhere on the board
A6: U7.4 (A6); also elsewhere on the board
A7: U7.3 (A7); also elsewhere on the board
A8: U7.25 (A8); also elsewhere on the board
A9: U7.24 (A9); also elsewhere on the board
A10: U7.21 (A10); also elsewhere on the board
A11: U7.23 (A11); also elsewhere on the board
A12: U7.2 (A12); also elsewhere on the board
A13: U7.26 (A13); also elsewhere on the board
D0: U7.11 (D0); also elsewhere on the board
D1: U7.12 (D1); also elsewhere on the board
D2: U7.13 (D2); also elsewhere on the board
D3: U7.15 (D3); also elsewhere on the board
D4: U7.16 (D4); also elsewhere on the board
D5: U7.17 (D5); also elsewhere on the board
D6: U7.18 (D6); also elsewhere on the board
D7: U7.19 (D7); also elsewhere on the board
GND: C253.2, J51.5, J51.6, U7.14 (GND); also elsewhere on the board
unnamed: J51.3, U7.1 (A15)
unnamed: J51.4, U7.27 (A14)
OS: U7.20 (~CE), U7.22 (~OE); also elsewhere on the board
VCC: C253.1, J51.1, J51.2, U7.28 (VCC); also elsewhere on the board

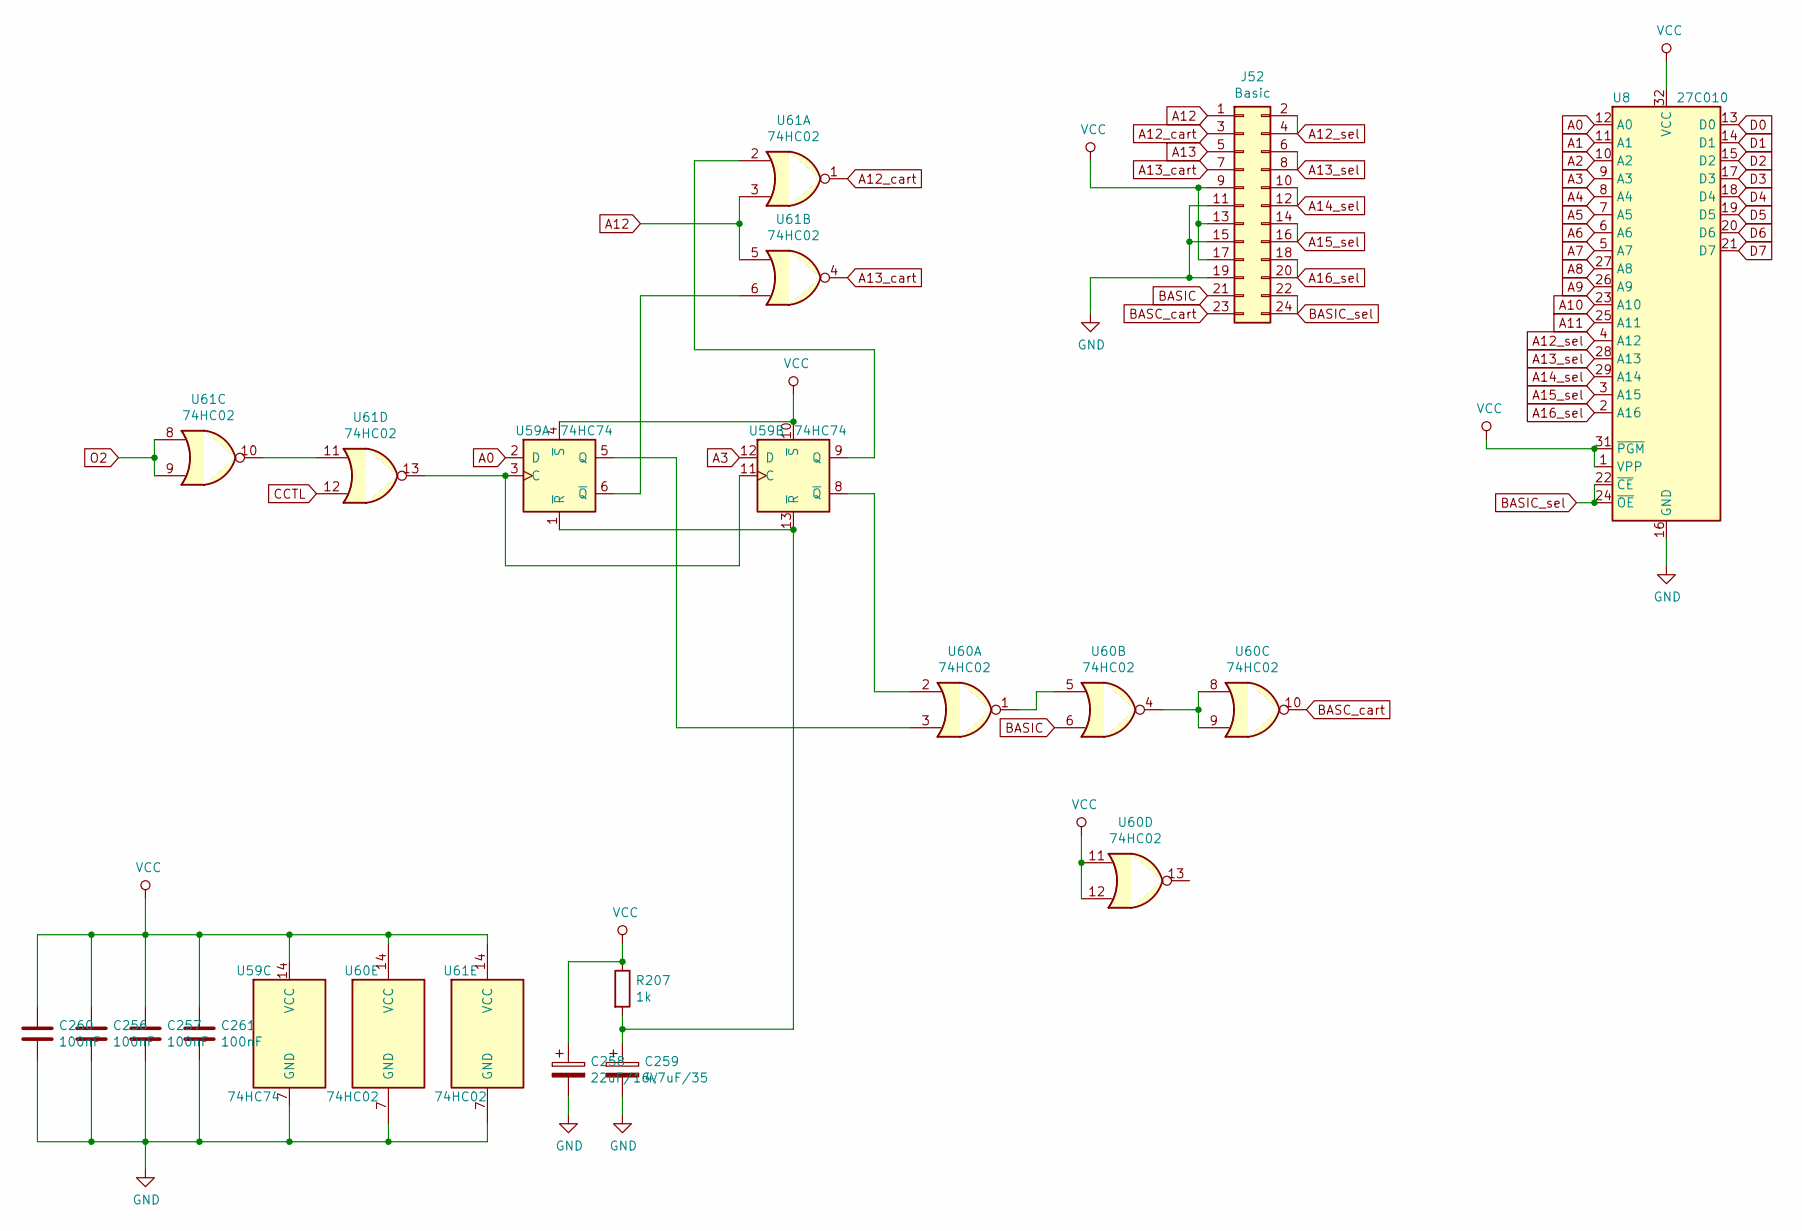
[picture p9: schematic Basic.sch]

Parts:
C256: 100nF; C_Disc_D6.0mm_W2.5mm_P5.00mm
C257, C260, C261: 100nF; C_1206_3216Metric_Pad1.42x1.75mm_HandSolder
C258: 22uF/16V; CP_Elec_4x5.3
C259: 4,7uF/35; CP_Elec_4x5.3
J52: Basic; PinHeader_2x12_P2.54mm_Vertical
R207: 1k; R_1206_3216Metric_Pad1.42x1.75mm_HandSolder
U8: 27C010; DIP-32_W15.24mm_Socket_LongPads
U59: 74HC74; SOIC-14_3.9x8.7mm_P1.27mm
U60, U61: 74HC02; SOIC-14_3.9x8.7mm_P1.27mm

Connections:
A0: U8.12 (A0), U59.2 (D); also elsewhere on the board
A1: U8.11 (A1); also elsewhere on the board
A2: U8.10 (A2); also elsewhere on the board
A3: U8.9 (A3), U59.12 (D); also elsewhere on the board
A4: U8.8 (A4); also elsewhere on the board
A5: U8.7 (A5); also elsewhere on the board
A6: U8.6 (A6); also elsewhere on the board
A7: U8.5 (A7); also elsewhere on the board
A8: U8.27 (A8); also elsewhere on the board
A9: U8.26 (A9); also elsewhere on the board
A10: U8.23 (A10); also elsewhere on the board
A11: U8.25 (A11); also elsewhere on the board
A12: J52.1, U61.3, U61.5; also elsewhere on the board
A12_cart: J52.3, U61.1
A12_sel: J52.2, J52.4, U8.4 (A12)
A13: J52.5; also elsewhere on the board
A13_cart: J52.7, U61.4
A13_sel: J52.6, J52.8, U8.28 (A13)
A14_sel: J52.10, J52.12, U8.29 (A14)
A15_sel: J52.14, J52.16, U8.3 (A15)
A16_sel: J52.18, J52.20, U8.2 (A16)
BASC_cart: J52.23, U60.10
BASIC: J52.21, U60.6; also elsewhere on the board
BASIC_sel: J52.22, J52.24, U8.22 (~CE), U8.24 (~OE)
CCTL: U61.12; also elsewhere on the board
D0: U8.13 (D0); also elsewhere on the board
D1: U8.14 (D1); also elsewhere on the board
D2: U8.15 (D2); also elsewhere on the board
D3: U8.17 (D3); also elsewhere on the board
D4: U8.18 (D4); also elsewhere on the board
D5: U8.19 (D5); also elsewhere on the board
D6: U8.20 (D6); also elsewhere on the board
D7: U8.21 (D7); also elsewhere on the board
GND: C256.2, C257.2, C258.2, C259.2, C260.2, C261.2, J52.11, J52.15, J52.19, U8.16 (GND), U59.7 (GND), U60.7 (GND), U61.7 (GND); also elsewhere on the board
unnamed: C259.1, R207.2, U59.1 (~R), U59.13 (~R)
unnamed: U59.5 (Q), U60.3
unnamed: U59.6 (~Q), U61.6
unnamed: U59.8 (~Q), U60.2
unnamed: U59.9 (Q), U61.2
unnamed: U59.3 (C), U59.11 (C), U61.13
unnamed: U60.1, U60.5
unnamed: U60.4, U60.8, U60.9
unnamed: U61.10, U61.11
O2: U61.8, U61.9; also elsewhere on the board
VCC: C256.1, C257.1, C258.1, C260.1, C261.1, J52.9, J52.13, J52.17, R207.1, U8.1 (VPP), U8.31 (~PGM), U8.32 (VCC), U59.4 (~S), U59.10 (~S), U59.14 (VCC), U60.11, U60.12, U60.14 (VCC), U61.14 (VCC); also elsewhere on the board

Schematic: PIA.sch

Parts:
C29: 100nF; C_Disc_D5.0mm_W2.5mm_P5.00mm
FB10, FB11, FB12, FB13: Ferrite_Bead; L_Axial_L9.5mm_D4.0mm_P12.70mm_Horizontal_Fastron_SMCC
J4, J5: Joystick_Port; Joystick_Pport
Q4: 2N3906; TO-92
R8, R9, R10, R11, R13, R30, R31, R32, R34: 3k; R_1206_3216Metric_Pad1.42x1.75mm_HandSolder
R74, R75, R76, R77, R78, R79, R80, R81: 120; R_1206_3216Metric_Pad1.42x1.75mm_HandSolder
R82, R83, R84: 4k7; R_1206_3216Metric_Pad1.42x1.75mm_HandSolder
R85, R86, R87: 100; R_1206_3216Metric_Pad1.42x1.75mm_HandSolder
R88: 2k7; R_1206_3216Metric_Pad1.42x1.75mm_HandSolder
U1: PIA; DIP-40_W15.24mm_LongPads

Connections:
A0: U1.35 (A0); also elsewhere on the board
A1: U1.36 (A1); also elsewhere on the board
BACK0: J4.2 (Back), R75.1
BACK1: J5.2 (Back), R79.1
BO2: U1.25 (O2); also elsewhere on the board
COMMAND: R85.2; also elsewhere on the board
D0: U1.33 (D0); also elsewhere on the board
D1: U1.32 (D1); also elsewhere on the board
D2: U1.31 (D2); also elsewhere on the board
D3: U1.30 (D3); also elsewhere on the board
D4: U1.29 (D4); also elsewhere on the board
D5: U1.28 (D5); also elsewhere on the board
D6: U1.27 (D6); also elsewhere on the board
D7: U1.26 (D7); also elsewhere on the board
FWD0: J4.1 (FWD), R74.1
FWD1: J5.1 (FWD), R78.1
GND: C29.2, J4.8 (GND), J5.8 (GND), U1.1 (VSS); also elsewhere on the board
INTERRUPT: R86.2; also elsewhere on the board
IRQ: U1.37 (~IRQB), U1.38 (~IRQA); also elsewhere on the board
LEFT0: J4.3 (Left), R76.1
LEFT1: J5.3 (Left), R80.1
MTRCTL: FB10.1; also elsewhere on the board
unnamed: FB10.2, Q4.3 (C)
unnamed: FB12.1, J4.7 (VCC)
unnamed: FB13.1, J5.7 (VCC)
unnamed: Q4.2 (B), R88.2
unnamed: R8.2, U1.22 (CS0), U1.24 (CS1)
unnamed: R74.2, U1.2 (PA0)
unnamed: R75.2, U1.3 (PA1)
unnamed: R76.2, U1.4 (PA2)
unnamed: R77.2, U1.5 (PA3)
unnamed: R78.2, U1.6 (PA4)
unnamed: R79.2, U1.7 (PA5)
unnamed: R80.2, U1.8 (PA6)
unnamed: R81.2, U1.9 (PA7)
unnamed: R82.1, R86.1, U1.18 (CB1)
unnamed: R83.1, R85.1, U1.19 (CB2)
unnamed: R84.1, R87.1, U1.40 (CA1)
unnamed: R88.1, U1.39 (CA2)
PB0: R9.2, U1.10 (PB0); also elsewhere on the board
PB1: R10.2, U1.11 (PB1); also elsewhere on the board
PB2: R11.2, U1.12 (PB2); also elsewhere on the board
PB3: R13.2, U1.13 (PB3); also elsewhere on the board
PB4: R30.2, U1.14 (PB4); also elsewhere on the board
PB5: R31.2, U1.15 (PB5); also elsewhere on the board
PB6: R32.2, U1.16 (PB6); also elsewhere on the board
PB7: R34.2, U1.17 (PB7); also elsewhere on the board
PIA: U1.23 (~CS2); also elsewhere on the board
POTA01: J4.9 (Pot_A); also elsewhere on the board
POTA02: J5.9 (Pot_A); also elsewhere on the board
POTB01: J4.5 (Pot_B); also elsewhere on the board
POTB02: J5.5 (Pot_B); also elsewhere on the board
PROCEED: R87.2; also elsewhere on the board
READY: FB11.1; also elsewhere on the board
RIGHT0: J4.4 (Right), R77.1
RIGHT1: J5.4 (Right), R81.1
RST: U1.34 (~RST); also elsewhere on the board
R\W: U1.21 (R/~W); also elsewhere on the board
TRIG0: J4.6 (Trig); also elsewhere on the board
TRIG1: J5.6 (Trig); also elsewhere on the board
VCC: C29.1, FB11.2, FB12.2, FB13.2, Q4.1 (E), R8.1, R9.1, R10.1, R11.1, R13.1, R30.1, R31.1, R32.1, R34.1, R82.2, R83.2, R84.2, U1.20 (VCC); also elsewhere on the board

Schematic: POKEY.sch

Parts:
C30, C31, C32, C33: 47nF; C_1206_3216Metric_Pad1.42x1.75mm_HandSolder
C34: 22uF; CP_Elec_6.3x5.3
C35, C36, C49: 100nF; C_Disc_D5.0mm_W2.5mm_P5.00mm
C37: 10nF; C_1206_3216Metric_Pad1.42x1.75mm_HandSolder
C38: 100nF; C_1206_3216Metric_Pad1.42x1.75mm_HandSolder
D5: 1N4148; D_MiniMELF_Handsoldering
J6: Keyboard; PinHeader_1x24_P2.54mm_Vertical
J15: SIO_Port; SIO_Slot
R54, R142: 1k; R_1206_3216Metric_Pad1.42x1.75mm_HandSolder
R55, R56, R57, R58, R139: 100; R_1206_3216Metric_Pad1.42x1.75mm_HandSolder
R59, R60, R61, R62: 4k7; R_1206_3216Metric_Pad1.42x1.75mm_HandSolder
R63, R64, R65, R66: 1k8; R_1206_3216Metric_Pad1.42x1.75mm_HandSolder
R89, R141: 47k; R_1206_3216Metric_Pad1.42x1.75mm_HandSolder
R90: 3k; R_1206_3216Metric_Pad1.42x1.75mm_HandSolder
R117, R118, R119, R120, R121, R122, R123, R124, R125, R126, R127, R128, R129, R130, R137, R138: 220; R_1206_3216Metric_Pad1.42x1.75mm_HandSolder
R140: 270; R_1206_3216Metric_Pad1.42x1.75mm_HandSolder
U5: POKEY; DIP-40_W15.24mm_LongPads
U62, U63: 4051; DIP-16_W7.62mm_Socket

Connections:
A0: U5.36 (A0); also elsewhere on the board
A1: U5.35 (A1); also elsewhere on the board
A2: U5.34 (A2); also elsewhere on the board
A3: U5.33 (A3); also elsewhere on the board
BO2: U5.7 (O2); also elsewhere on the board
BSC: J6.20, R140.1
CLKIN: J15.1 (CLK_IN), R56.1
CLKOUT: J15.2 (CLK_OUT), R55.1
COMMAND: J15.7 (Command); also elsewhere on the board
D0: U5.38 (D0); also elsewhere on the board
D1: U5.39 (D1); also elsewhere on the board
D2: U5.40 (D2); also elsewhere on the board
D3: U5.2 (D3); also elsewhere on the board
D4: U5.3 (D4); also elsewhere on the board
D5: U5.4 (D5); also elsewhere on the board
D6: U5.5 (D6); also elsewhere on the board
D7: U5.6 (D7); also elsewhere on the board
DATAIN: J15.3 (Data_In), R57.1
DATAOUT: J15.5 (Data_Out), R58.1
GND: C30.2, C31.2, C32.2, C33.2, C34.2, C35.2, C36.2, C37.2, C38.2, C49.2, J6.3, J15.4 (GND), J15.6 (GND), R139.2, U5.1 (VSS), U5.8 (P6), U5.9 (P7), U5.10 (P4), U5.11 (P5), U62.6 (Inh), U62.7 (VEE), U62.8 (VSS), U63.6 (Inh), U63.7 (VEE), U63.8 (VSS); also elsewhere on the board
IN0: J6.17, R117.1
IN1: J6.11, R118.1
IN2: J6.8, R119.1
IN3: J6.16, R120.1
IN4: J6.19, R121.1
IN5: J6.10, R122.1
IN6: J6.4, R123.1
IN7: J6.9, R124.1
INTERRUPT: J15.13 (Intrupt); also elsewhere on the board
IRQ: U5.29 (~IRQ); also elsewhere on the board
K0: U5.23 (~K0), U62.11 (A)
K1: U5.22 (~K1), U62.10 (B)
K2: U5.21 (~K2), U62.9 (C)
K3: U5.20 (~K3), U63.11 (A)
K4: U5.19 (~K4), U63.10 (B)
K5: U5.18 (~K5), U63.9 (C)
KR1: R89.1, U5.25 (~KR1), U62.3 (X)
MTRCTL: J15.8 (Mtr_Ctrl); also elsewhere on the board
unnamed: C30.1, R66.2, U5.12 (P2)
unnamed: C31.1, R65.2, U5.13 (P3)
unnamed: C32.1, R64.2, U5.14 (P0)
unnamed: C33.1, R63.2, U5.15 (P1)
unnamed: C37.1, J6.2, R142.1
unnamed: D5.2 (A), R140.2, R141.2, U5.16 (~KR2)
unnamed: R55.2, R59.2, U5.27 (ACLK)
unnamed: R56.2, R60.2, U5.26 (BCLK)
unnamed: R57.2, R61.2, U5.24 (SID)
unnamed: R58.2, R62.2, U5.28 (SOD)
unnamed: R90.1, U5.31 (CS1)
unnamed: R117.2, U62.13 (X0)
unnamed: R118.2, U62.14 (X1)
unnamed: R119.2, U62.15 (X2)
unnamed: R120.2, U62.12 (X3)
unnamed: R121.2, U62.1 (X4)
unnamed: R122.2, U62.5 (X5)
unnamed: R123.2, U62.2 (X6)
unnamed: R124.2, U62.4 (X7)
unnamed: R125.2, U63.13 (X0)
unnamed: R126.2, U63.14 (X1)
unnamed: R127.2, U63.15 (X2)
unnamed: R128.2, U63.12 (X3)
unnamed: R129.2, U63.1 (X4)
unnamed: R130.2, U63.5 (X5)
unnamed: R137.2, U63.2 (X6)
unnamed: R138.2, U63.4 (X7)
unnamed: R139.1, U63.3 (X)
OPTION: J6.23; also elsewhere on the board
OUT0: J6.18, R125.1
OUT1: J6.13, R126.1
OUT2: J6.15, R127.1
OUT3: J6.5, R128.1
OUT4: J6.14, R129.1
OUT5: J6.6, R130.1
OUT6: J6.12, R137.1
OUT7: J6.7, R138.1
POKEY: U5.30 (~CS0); also elsewhere on the board
POTA01: R64.1; also elsewhere on the board
POTA02: R66.1; also elsewhere on the board
POTB01: R63.1; also elsewhere on the board
POTB02: R65.1; also elsewhere on the board
PROCEED: J15.9 (Proceed); also elsewhere on the board
READY: C34.1, J15.10 (VCC); also elsewhere on the board
RESET: J6.24; also elsewhere on the board
R\W: U5.32 (R/~W); also elsewhere on the board
SELECT: J6.22; also elsewhere on the board
SIOAUDIO: J15.11 (SIO_Audio); also elsewhere on the board
SOUND: R54.2, U5.37 (AUDIO); also elsewhere on the board
START: J6.21; also elsewhere on the board
VCC: C35.1, C36.1, C38.1, C49.1, D5.1 (K), J6.1, R54.1, R59.1, R60.1, R61.1, R62.1, R89.2, R90.2, R141.1, R142.2, U5.17 (VCC), U62.16 (VDD), U63.16 (VDD); also elsewhere on the board

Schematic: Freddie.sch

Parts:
C21, C22: 27pF; C_1206_3216Metric_Pad1.42x1.75mm_HandSolder
C23, C24, C25, C26: 100nF; C_Disc_D5.0mm_W2.5mm_P5.00mm
J3: Cartridge; Cartridge_Slot
R1, R2, R3, R12, R114: 3k; R_1206_3216Metric_Pad1.42x1.75mm_HandSolder
R14, R15: 1k; R_1206_3216Metric_Pad1.42x1.75mm_HandSolder
R16: 240; R_1206_3216Metric_Pad1.42x1.75mm_HandSolder
R17: 1M; R_1206_3216Metric_Pad1.42x1.75mm_HandSolder
U9: Freddie; DIP-40_W15.24mm_LongPads
U10: 74LS08; DIP-14_W7.62mm_Socket
U13: 74LS138; DIP-16_W7.62mm_Socket
U14: MMU; DIP-20_W7.62mm_LongPads
Y1: 14,18757MHz; Crystal_HC18-U_Horizontal

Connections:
A0: J3.5 (A0), U9.8 (A0); also elsewhere on the board
A1: J3.4 (A1), U9.9 (A1); also elsewhere on the board
A2: J3.3 (A2), U9.10 (A2); also elsewhere on the board
A3: J3.2 (A3), U9.11 (A3); also elsewhere on the board
A4: J3.C (A4), U9.12 (A4); also elsewhere on the board
A5: J3.D (A5), U9.13 (A5); also elsewhere on the board
A6: J3.E (A6), U9.14 (A6); also elsewhere on the board
A7: J3.F (A7), U9.15 (A7); also elsewhere on the board
A8: J3.H (A8), U9.16 (A8), U13.1 (A0); also elsewhere on the board
A9: J3.J (A9), U9.17 (A9), U13.2 (A1); also elsewhere on the board
A10: J3.P (A10), U9.18 (A10), U13.3 (A2); also elsewhere on the board
A11: J3.N (A11), U9.19 (A11), U14.1 (A11); also elsewhere on the board
A12: J3.K (A12), U9.21 (A12), U14.2 (A12); also elsewhere on the board
A13: U9.22 (A13), U14.3 (A13); also elsewhere on the board
A14: U14.4 (A14); also elsewhere on the board
A15: U14.5 (A15); also elsewhere on the board
BASIC: U14.13 (~BASIC); also elsewhere on the board
BO2: J3.S (O2), U10.3; also elsewhere on the board
CAS: U9.35 (~CAS); also elsewhere on the board
CASINH: U9.4 (~CASINH), U14.16 (~CI)
CCTL: J3.15 (~CCTL), U13.10 (O5); also elsewhere on the board
D0: J3.10 (D0); also elsewhere on the board
D1: J3.9 (D1); also elsewhere on the board
D2: J3.8 (D2); also elsewhere on the board
D3: J3.L (D3); also elsewhere on the board
D4: J3.6 (D4); also elsewhere on the board
D5: J3.7 (D5); also elsewhere on the board
D6: J3.11 (D6); also elsewhere on the board
D7: J3.M (D7); also elsewhere on the board
EXTSEL: R1.1, U9.3 (~EXTSEL)
FA14: U9.23 (A14); also elsewhere on the board
FA15: U9.24 (A15); also elsewhere on the board
GND: C21.2, C22.2, C23.2, C24.2, C25.2, C26.2, J3.B (GND), R14.1, R15.1, U9.20 (VSS), U13.5 (E2), U13.8 (GND), U14.10 (VSS); also elsewhere on the board
GTIA: U10.8; also elsewhere on the board
MPD: R114.1, U14.14 (~MPD)
unnamed: C21.1, R16.2, Y1.1
unnamed: C22.1, R17.2, U9.2 (CLK), Y1.2
unnamed: R3.1, U10.2
unnamed: R12.1, U13.6 (E3)
unnamed: R16.1, R17.1, U9.1 (CLK0)
unnamed: U10.9, U10.10, U13.15 (O0)
unnamed: U13.4 (E1), U14.17 (~IO)
O2: R2.1, U9.5 (O2), U10.1; also elsewhere on the board
OS: U14.15 (~OS); also elsewhere on the board
OSC: U9.37 (OSC); also elsewhere on the board
PB0: U14.9 (REN); also elsewhere on the board
PB1: U14.18 (~BE); also elsewhere on the board
PB7: U14.6 (~MAP); also elsewhere on the board
PIA: U13.12 (O3); also elsewhere on the board
POKEY: U13.13 (O2); also elsewhere on the board
RA0: U9.32 (RA0); also elsewhere on the board
RA1: U9.31 (RA1); also elsewhere on the board
RA2: U9.30 (RA2); also elsewhere on the board
RA3: U9.29 (RA3); also elsewhere on the board
RA4: U9.28 (RA4); also elsewhere on the board
RA5: U9.27 (RA5); also elsewhere on the board
RA6: U9.26 (RA6); also elsewhere on the board
RA7: U9.25 (RA7); also elsewhere on the board
RAS: U9.33 (~RAS); also elsewhere on the board
RD4: J3.A (RD4), R14.2, U14.7 (RD4)
RD5: J3.14 (RDS), R15.2, U14.8 (RD5); also elsewhere on the board
REF: U14.11 (~REF); also elsewhere on the board
RST: U9.39 (RST); also elsewhere on the board
R\W: J3.R (R/~W), U9.38 (R/~W); also elsewhere on the board
S4: J3.1 (~S4), U14.19 (~S4)
S5: J3.12 (~S5), U14.12 (~S5)
VCC: C23.1, C24.1, C25.1, C26.1, J3.13 (VCC), R1.2, R2.2, R3.2, R12.2, R114.2, U9.40 (VCC), U13.16 (VCC), U14.20 (VCC); also elsewhere on the board
WRT: U9.34 (~WRT); also elsewhere on the board

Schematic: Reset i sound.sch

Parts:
C40, C42: 100n; C_1206_3216Metric_Pad1.42x1.75mm_HandSolder
D6: 1N4001; D_MiniMELF_Handsoldering
R91: 100; R_1206_3216Metric_Pad1.42x1.75mm_HandSolder
R92: 56k; R_1206_3216Metric_Pad1.42x1.75mm_HandSolder
R93: 470k; R_1206_3216Metric_Pad1.42x1.75mm_HandSolder
U21: NE555; DIP-8_W7.62mm_LongPads

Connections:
GND: D6.2 (A), R93.2, U21.1 (GND); also elsewhere on the board
unnamed: C40.1, C42.2, D6.1 (K), R93.1, U21.2 (TR), U21.6 (THR)
unnamed: C40.2, R91.1, R92.2
RESET: R91.2; also elsewhere on the board
RST: U21.3 (Q); also elsewhere on the board
VCC: C42.1, R92.1, U21.4 (R), U21.8 (VCC); also elsewhere on the board

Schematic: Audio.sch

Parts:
C98, C103: 47nF; C_1206_3216Metric_Pad1.42x1.75mm_HandSolder
C99, C100: 4,7uF; C_Radial_D8.0mm_H7.0mm_P3.50mm
C101, C102: 1nF; C_1206_3216Metric_Pad1.42x1.75mm_HandSolder
C104: 10uF; CP_Elec_6.3x5.3
C105: 100nF; C_1206_3216Metric_Pad1.42x1.75mm_HandSolder
R143: 56k; R_1206_3216Metric_Pad1.42x1.75mm_HandSolder
R144, R152: 2k2; R_1206_3216Metric_Pad1.42x1.75mm_HandSolder
R145: 6k2; R_1206_3216Metric_Pad1.42x1.75mm_HandSolder
R146, R151: 1k; R_1206_3216Metric_Pad1.42x1.75mm_HandSolder
R147: 2k; R_1206_3216Metric_Pad1.42x1.75mm_HandSolder
R148: 470k; R_1206_3216Metric_Pad1.42x1.75mm_HandSolder
R149: 68k; R_1206_3216Metric_Pad1.42x1.75mm_HandSolder
R150: 5k1; R_1206_3216Metric_Pad1.42x1.75mm_HandSolder
R153: 3k3; R_1206_3216Metric_Pad1.42x1.75mm_HandSolder
U64: LM358; DIP-8_W7.62mm_Socket_LongPads

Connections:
+5VA: C105.2, R153.2, U64.8 (V+); also elsewhere on the board
AUDIO: R150.1, R151.2; also elsewhere on the board
BELL: C103.1; also elsewhere on the board
GND: C101.1, C102.1, C104.2, C105.1, R145.1, R151.1, R152.1, U64.4 (V-); also elsewhere on the board
unnamed: C98.1, R143.2
unnamed: C99.1, R147.2
unnamed: C99.2, C100.1, C102.2, R146.1
unnamed: C103.2, R148.2
unnamed: C104.1, R152.2, R153.1, U64.3 (+), U64.5 (+)
unnamed: R143.1, R144.2, U64.6 (-)
unnamed: R144.1, R145.2, R146.2, U64.7
unnamed: R147.1, R148.1, R149.2, U64.2 (-)
unnamed: R149.1, R150.2, U64.1
SIOAUDIO: C100.2, C101.2; also elsewhere on the board
SOUND: C98.2; also elsewhere on the board

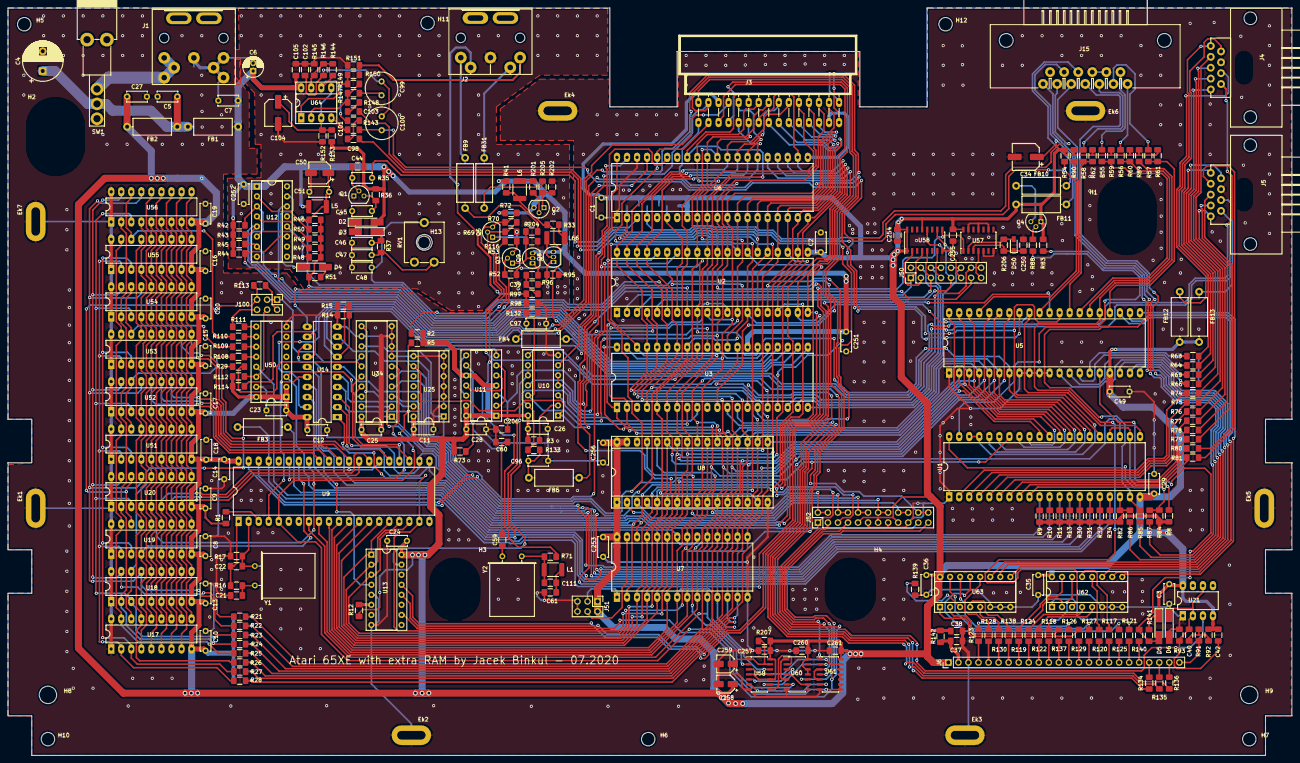
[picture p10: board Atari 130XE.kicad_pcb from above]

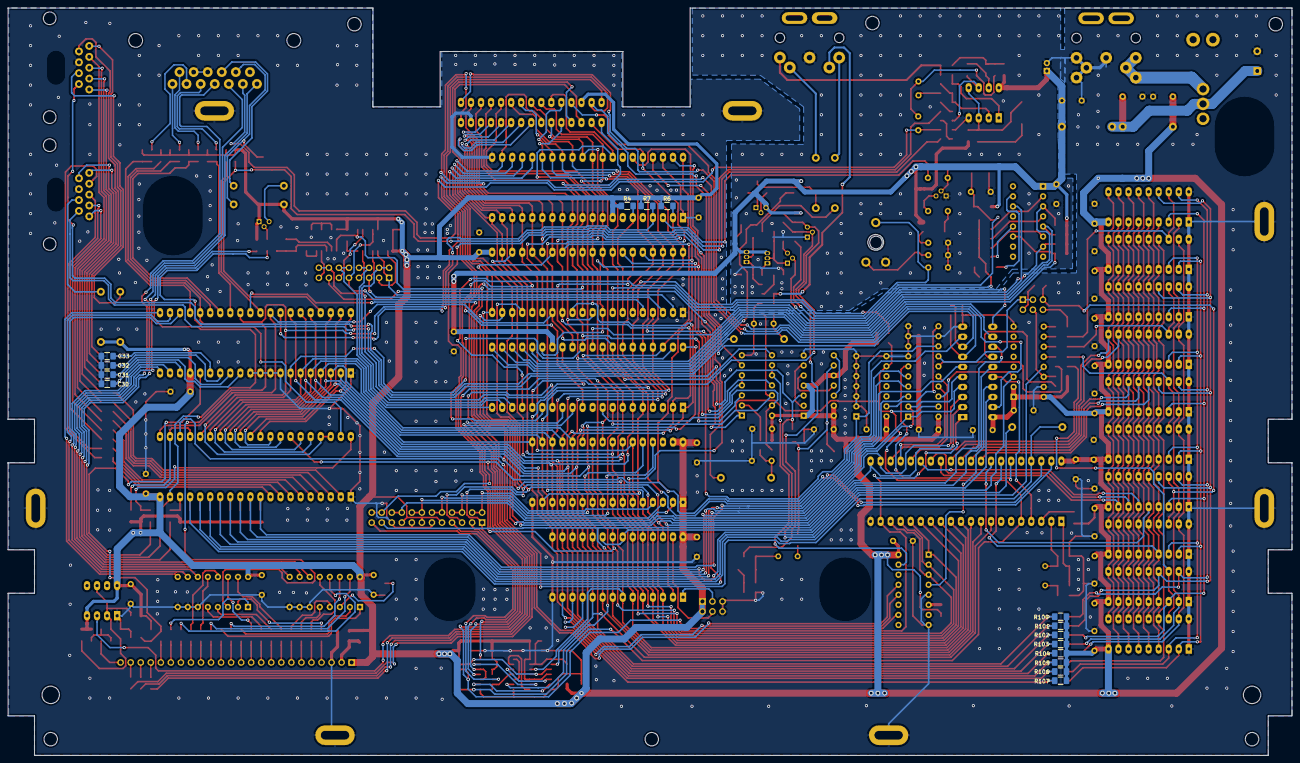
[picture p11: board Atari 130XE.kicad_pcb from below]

Board: 2 copper layers, 324.7 x 189.0 mm, 321 parts (15 on the bottom side), 305 nets.
